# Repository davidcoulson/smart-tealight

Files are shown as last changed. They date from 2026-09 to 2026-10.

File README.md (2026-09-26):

# smart-tealight

A rechargeable, 38 mm tea-light replacement with addressable LEDs, built on a
Seeed XIAO module, controlled from Home Assistant.

* **Fits a standard tea-light holder:** 38 mm Ø, ≤ 23 mm tall, 3D-printed PETG body
* **Battery powered:** ~400 mAh LiPo, charged over the XIAO's USB-C
* **Two light channels:** an 8-LED addressable ring for effects, and a single
  warm-white LED for a low-power flickering "candle" mode that lasts a week
* **Two firmware tracks on the same hardware:**
  * *Track A* — XIAO ESP32-C6 + [ESPHome](esphome/tealight-c6.yaml). Quick to
    build, ~½ day on battery because Wi-Fi stays associated. For prototyping.
  * *Track B* — the same XIAO ESP32-C6, [ESPHome over Thread](esphome/tealight-c6-thread.yaml)
    via the HA OpenThread Border Router. **Working on the bench (2026-09-26).**
    Next: sleepy end device + light sleep for weeks of standby.

**Status: design stage.** No hardware has been built; all current and battery
figures are estimates to be measured on the first prototype.

## Docs

* [Design notes](docs/design-notes.md) — prior art, power budget, mechanical
  stack, pin plan, bill of materials (Amazon US), firmware behaviour, next steps
* [Shopping list](docs/shopping-list.md) — Amazon US listings for every part
* [Wiring schematic](docs/wiring.svg) and [perfboard layout](docs/perfboard.svg) (generators alongside)

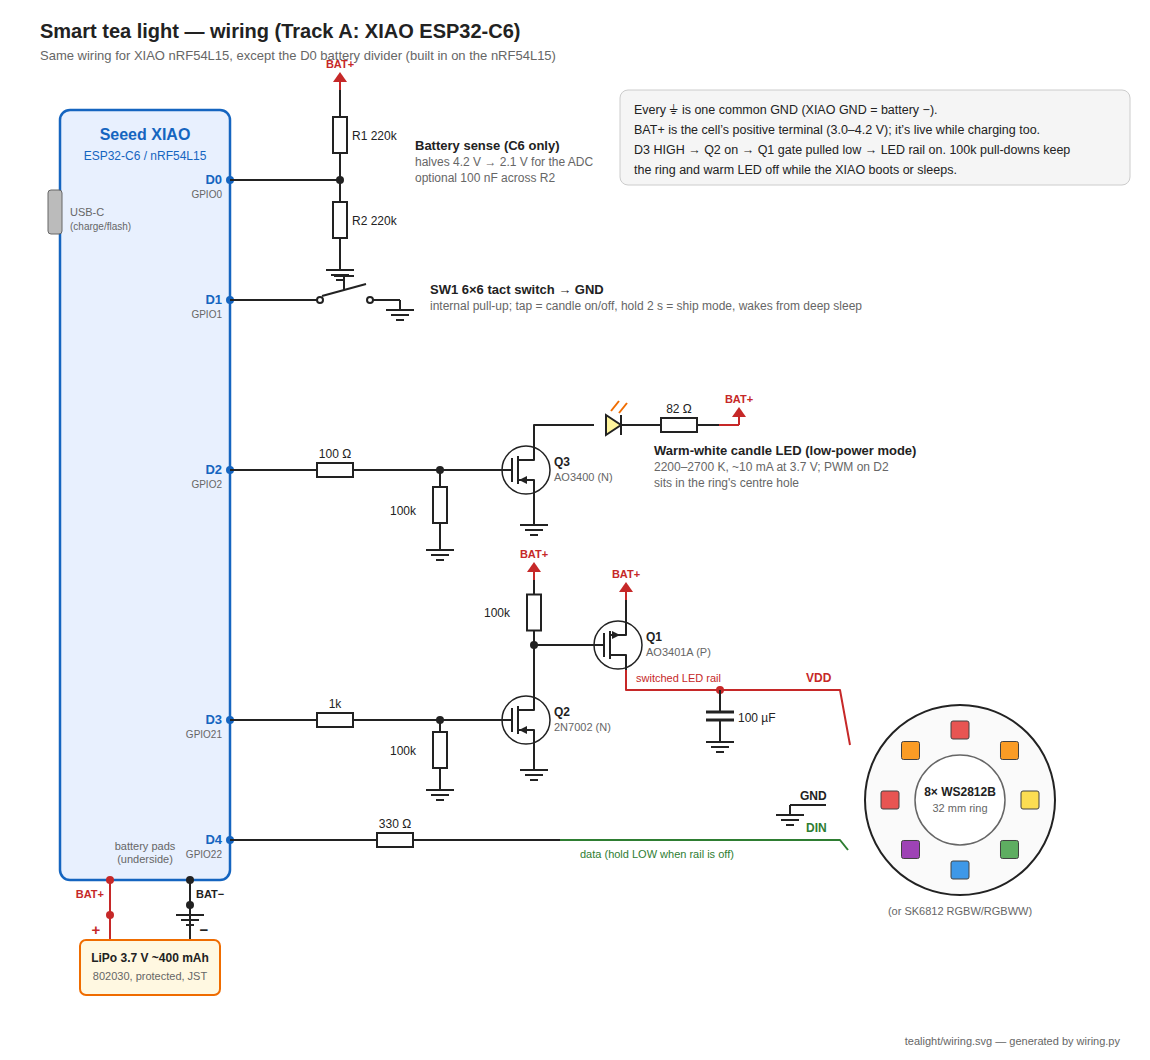
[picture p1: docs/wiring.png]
Wiring


## Repo layout

```
docs/       design notes, schematic and its generator
esphome/    Track A ESPHome config (XIAO ESP32-C6)
firmware/   fallback only: matter-thread-test/ (ESP-Matter procedure, not used)
hardware/   3D-printable body, later a custom LED PCB (to come)
```

## License

MIT — see [LICENSE](LICENSE).

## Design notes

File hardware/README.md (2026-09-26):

# Body — 3D-printed parts

`tealight.scad` is the source (parametric; every dimension at the top).
Three parts:

| Part | Material | Notes |
|---|---|---|
| `cup.stl` | opaque PETG | battery, perfboard ledge tabs, XIAO, USB-C notch (+x), Ø4 button hole in the floor |
| `carrier.stl` | opaque PETG | 4.5 mm spacer on the perfboard that carries the 32 mm LED ring; cut away over the XIAO |
| `cap.stl` | translucent PETG | diffuser, 2 mm plug skirt into the cup, notched for the USB-C |

Total height 23.0 mm, Ø38. Stack: floor 1 · cell 8.5 · perf 1.6 · XIAO 4 ·
ring 3.5 · headroom 2.9 · top 1.

Render: `openscad -D 'part="cup"' -o cup.stl tealight.scad` (same for
`carrier`, `cap`; `part="all"` with `exploded=true` for a preview).
`preview.py` is a manifold3d port used to produce the STLs and
`preview.png` where OpenSCAD isn't available; keep it in sync with the .scad.

**Untested — first print is a fit test.** Things to check on it: the 802030
cell's corners against the Ø36 bore, the USB-C notch height (12–15.5 mm)
against the real XIAO on the perfboard, and the cap's plug fit (0.2 mm
clearance; PETG usually wants 0.2–0.3).

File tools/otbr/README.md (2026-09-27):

# OTBR on a Linux box (USB RCP)

1. Flash `firmware/nrf52840-rcp` onto a XIAO nRF52840 (double-tap reset →
   `adafruit-nrfutil dfu serial --package rcp.zip -p /dev/cu.usbmodem101 -b 115200 --singlebank`)
   and plug it into the Linux box. It enumerates as "Thread RCP nRF52840",
   `/dev/ttyACM0` (check `ls -l /dev/serial/by-id/`).
2. `BACKBONE=<lan-if> docker compose up -d` in this directory.
3. Form a network once (the container keeps it in the `otbr-data` volume):
   `docker exec otbr ot-ctl dataset init new && docker exec otbr ot-ctl dataset commit active && docker exec otbr ot-ctl ifconfig up && docker exec otbr ot-ctl thread start`
   then `docker exec otbr ot-ctl state` → `leader`.
4. Home Assistant → Settings → Devices & services → Thread: the new border
   router appears (mDNS `_meshcop._udp`) → "Make preferred network".
5. Sanity check with the OT CLI board (`firmware/nrf52840-otcli`): join with
   `docker exec otbr ot-ctl dataset active -x`, `ot mode -`, 50 pings to the
   BR's ML-EID (`docker exec otbr ot-ctl ipaddr mleid`) — expect ~100 %.

Web UI: http://<box>:80, REST: http://<box>:8081/node.

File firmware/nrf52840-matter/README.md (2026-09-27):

# nRF52840 (XIAO BLE) — Matter over Thread, sleepy end device

Same app as `../nrf54-matter` (Nordic `light_bulb`, NCS v3.2.4) ported to the
**Seeed XIAO nRF52840** as the stand-in while the nRF54L15 is backordered.
Builds: 723 KB of the 784 KB app partition, 64 % RAM. **Boots and advertises Matter
over BLE on the XIAO nRF52840** (2026-09-27); commissioning is the next test.

Board specifics:
- `boards/xiao_ble_nrf52840.overlay` — PWM light on **P0.04 = D4**, console on the
  chip's own USB CDC ACM (the XIAO BLE has no debug probe), a `buttons` node on D5
  (Nordic's Matter glue requires one; nothing needs to be wired), die-temp sensor.
- `pm_static_xiao_ble_nrf52840.yml` — the board's Adafruit-bootloader layout
  (app at 0x27000 after MBR + SoftDevice reservation). It still reserves a 4 KB
  `factory_data` slot, but **factory data is off** (`CHIP_FACTORY_DATA=n`): the
  Adafruit bootloader only flashes the app image, so a generated factory-data
  partition never reaches the chip and the app sat silent at boot waiting for it.
  The build uses the CHIP test identity instead (VID 0xFFF1, PID 0x8005,
  discriminator 3840, passcode 20202021 — code `34970112332`).
- `prj.conf` additions — legacy USB stack only (`USB_DEVICE_STACK_NEXT=n`, both were
  linking), **MTD OpenThread library** (`OPENTHREAD_MTD=y`,
  `OPENTHREAD_NORDIC_LIBRARY_MTD=y` — the FTD set has no MTD lib), shells off, QSPI
  NOR off (unused, and it drags in an external-flash factory-data provider).

Build:
```sh
cd /opt/nordic/ncs/v3.2.4
nrfutil sdk-manager toolchain launch --ncs-version v3.2.4 -- \
  west build -p always -b xiao_ble/nrf52840 -d <this dir>/build <this dir> -- \
  -DSB_CONFIG_BOOTLOADER_NONE=y -DSB_CONFIG_MATTER_OTA=n -DSB_CONFIG_MATTER_FACTORY_DATA_GENERATE=n
```

Flash (double-tap reset first → green LED pulses, `XIAO-SENSE` mounts), either:
```sh
# serial DFU (what worked; the zip is made by the build)
adafruit-nrfutil dfu serial --package build/nrf52840-matter/zephyr/tealight.zip \
  -p /dev/cu.usbmodem101 -b 115200 --singlebank
```
or copy `build/nrf52840-matter/zephyr/zephyr.uf2` onto the `XIAO-SENSE` drive.
The board reboots as a "Tealight nRF52840" USB serial device carrying the log
(115200; on macOS it enumerates as a *new* `cu.usbmodem` port, not the bootloader's).
Commission: HA companion app → Settings → Devices → Add device → Matter, code
`34970112332` (BLE, so it has to be the phone app or a Matter server with a
Bluetooth adapter — the HA server's "Add device" only works if the host has BT).

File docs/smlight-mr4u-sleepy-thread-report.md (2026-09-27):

> **2026-09-27, later: DO NOT FILE.** The same failure reproduces with an SLZB-06
> (CC2652P) over USB on a separate Linux OTBR — see Finding 9 in
> `thread-sed-bisect-2026-09-26.md`. The MR4U is not the cause.

# SLZB-MR4U: Thread sleepy end devices cannot attach (indirect / CSL tx fails)

Report for SMLIGHT support — 2026-09-27.

## Summary

With the SLZB-MR4U's EFR32MG26 as the Thread radio, **rx-on Thread children work
but sleepy end devices (SED/SSED) never attach**: the border router queues the
Child ID Response for the sleeping child and every indirect (data-poll)
transmission fails, 4/4 attempts, on every attach. CSL (synchronized sleepy)
fails the same way. This happens both with the MR4U's built-in OTBR and with the
MR4U used as a network RCP by the Home Assistant OpenThread Border Router add-on
(stable and beta otbr-agent). Net effect: no battery-powered Matter-over-Thread
device can be commissioned through this radio.

## Hardware / firmware

| | |
|---|---|
| Device | SLZB-MR4U (hw 174), Ethernet mode, IPv6 "Off" in device settings, USB = debug port |
| Device firmware | v3.4.1.dev1 (dev channel) |
| Radio 1 | EFR32MG26, mode "Matter-over-Thread", firmware **20260416 (Dev)** — "Thread test firmware designed to fix problems with OTBR starting after device reboot" |
| RCP reported by otbr-agent | `SL-OPENTHREAD/3.0.1.0_GitHub-61e43cffb; EFR32; Apr 16 2026 06:14:46` |
| Radio 2 | CC2674P10, Zigbee coordinator (Zigbee2MQTT over tcp://10.2.4.5:7638) |
| Border router (config A) | MR4U built-in OTBR, network `SLZB-d6b5`, channel 15 |
| Border router (config B) | HA OpenThread Border Router add-on 3.2.0 on HA OS 18.3 (x86-64 VM), `network_device: 10.2.4.5:6638`, backbone `enp6s19` (same VLAN as the MR4U), tested with `beta: true` and `beta: false`; network `ha-thread-c912`, channel 15 |
| Test client | Seeed XIAO nRF52840, nRF Connect SDK v3.2.4 OpenThread CLI (`OPENTHREAD/ncs-thread-reference-20250402`), TX 0 dBm, same room; also an ESP32-C6 (ESPHome openthread) and the nRF52840 running Nordic's Matter `light_bulb` sample — all show the same behaviour |

Link quality between the MR4U and the test client is excellent in every test
(`ot parent`: Link Quality In 3 / Out 3; MR4U hears the client at about −68 dBm).

## Config A — MR4U built-in OTBR

Client joined as an rx-on MTD child (`ot mode rn`):

| test | result |
|---|---|
| attach | OK, parent = MR4U (RLOC 0xe000) |
| `ot ping <BR RLOC fd50:…:0:ff:fe00:e000>` ×10 | 9/10 answered, 23–51 ms, hlim 64 |
| `ot ping <BR mesh-local EID fd50:…:810:effc:8ad7:1b82>` (the SRP server address) ×10 | **2/10 answered**, hlim 255 |
| `ot srp client` registration of `_matter._tcp` | never reaches *Registered* (Adding → Refreshing forever) |

Consequence: a Matter device (Nordic light_bulb on nRF52840, sleepy or not)
gets through BLE commissioning, attaches to Thread, then logs
`SRP update error: timed out waiting on server response` ~14 times in a row (one
random success), so operational discovery fails and the commissioner's
fail-safe expires ("Commissioning failed: 32"). ESP32-C6/ESPHome behaves the
same as an MTD; as an FTD it happens to work.

## Config B — HA OTBR add-on, MR4U as network RCP

Same client, rx-on MTD child (`ot mode rn`):

| test | result |
|---|---|
| attach | OK, parent = add-on BR (RLOC 0x7000), LQI 3/3 |
| ping BR RLOC ×20 | 18/20, 24–40 ms |
| ping BR mesh-local EID ×20 | 13/20 |
| SRP registration | **Registered** in < 8 s (add-on log: `SrpServer: Send success response with granted lease: 7200`) |

Same client switched to a **sleepy end device** (`ot pollperiod 500`, `ot mode -`):

- `ot state` stays `detached` indefinitely (retested after 15 s, 20 s, and with
  `ot thread stop/start`). The client sends data polls (`TxDataPoll` counter
  increments) and the add-on receives its Child ID Requests.
- otbr-agent log, repeated on every attach attempt:
  ```
  Mle: Receive Child ID Request (fe80::4025:602e:becd:e0ac)
  Settings: Added ChildInfo {rloc:0x7001, extaddr:4225602ebecde0ac, timeout:240, mode:0x04, version:5}
  Mle: Send Child ID Response (fe80::4025:602e:becd:e0ac,0x7001)
  DataPollHandlr: Indirect tx to child 7001 failed, attempt 1/4
  DataPollHandlr: Indirect tx to child 7001 failed, attempt 2/4
  DataPollHandlr: Indirect tx to child 7001 failed, attempt 3/4
  DataPollHandlr: Indirect tx to child 7001 failed, attempt 4/4
  ```
- Identical with `beta: false` (stable otbr-agent) and `beta: true`.

Same client as a **synchronized sleepy end device** (`ot csl period 500000`):

- never attaches; otbr-agent log:
  ```
  CslTxScheduler: CSL tx to 7001 failed, attempt 1/4 … 4/4
  ```

Switching the client back to `ot mode rn` → attaches within seconds every time.

## EFR32 firmware 20251218 (Thread RCP 2.7.2.0, SDK 2025.6.2)

Re-flashed radio 1 to the older release build (`SL-OPENTHREAD/2.7.2.0_GitHub-fb0446f53;
EFR32; Dec 18 2025`), OTBR add-on stable, same client:

- sleepy child (`ot mode -`, poll 500 ms) **now attaches** and stays attached;
  SRP registration succeeds while sleepy.
- but delivery to the sleeping child is still poor: 50 pings to the BR's
  ML-EID → 21 answered (42 %), RTT 70 ms – 2.7 s; RLOC similar. otbr-agent
  still logs `Indirect tx to child … failed, attempt 1/4` on most frames, with
  some reaching 4/4 and being dropped. The client's MAC counters show every
  data poll ACKed (`TxAckRequested 675 / TxAcked 675`).
- To rule out host→RCP latency, the client was rebuilt with OpenThread's
  `OPENTHREAD_CONFIG_MAC_DATA_POLL_TIMEOUT` raised from 100 ms to 500 ms
  (radio kept on 5× longer after a frame-pending poll): 17/50 and 20/50 —
  **no improvement**. The queued frame is not reaching the child at all in
  the failing cases, so this is not host-side latency.

So: 3.0.1 build = sleepy children never attach; 2.7.2 build = attach, ~40 %
delivery. Both unusable for battery Matter devices.

## Interpretation

Direct transmissions to an rx-on child work; the two transmission paths that
depend on the RCP (frame-pending / source-address-match after a data poll, and
CSL-timed transmission) fail 100 % on the 3.0.1 build and ~60 % on the 2.7.2
build. Widening the child's listen window does not help, so the frames are
being lost between otbr-agent and the air, not arriving late. The same radio drives the MR4U's own
OTBR, which explains config A's SRP/ML-EID failures as well.

## How to reproduce

1. MR4U radio 1 in "Matter-over-Thread" mode; HA OTBR add-on with
   `network_device: <mr4u-ip>:6638`, form a network.
2. Any OpenThread CLI device (nRF52840 DK/dongle, or `ot-cli-ftd` on an
   EFR32 dev kit): `ot dataset set active <tlvs>`, `ot ifconfig up`,
   `ot thread start`, `ot mode rn` → attaches.
3. `ot pollperiod 500`, `ot mode -` → stays `detached`; watch the add-on log for
   `Indirect tx to child … failed`.
4. Alternatively commission any battery Matter-over-Thread device — it will
   fail after the Thread join.

## Questions for SMLIGHT

- Is indirect (data-poll) and CSL delivery to sleepy children known to be
  broken in the 20260416 EFR32MG26 Thread firmware, or in the network-RCP
  socket path on the MR4U?
- Is there a stable "Matter-over-Thread" firmware for the EFR32MG26 that we
  should test instead of the dev build?

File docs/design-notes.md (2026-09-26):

# Smart tea light — design notes

A 38 mm tea-light replacement: rechargeable, addressable RGB + warm white,
3D-printed body, controlled from Home Assistant singly or as a group.

Status: **design / pre-prototype** (2026-09-26). No hardware built yet. Every
current and runtime figure below is an estimate to confirm with a meter (a
Nordic PPK2 or a USB power meter on the charge port) on the first prototype.

## 1. Prior art — nothing does all of this yet

| Project | What it is | Why it isn't the answer |
|---|---|---|
| [PixelTheater/espcandle-demo](https://github.com/PixelTheater/espcandle-demo) | 38.6 × 20 mm custom PCB stack, ESP32-S3, 20× WS2812 + 2700 K white + red + UV, ESPHome, MIT | **No battery** — USB-C or 6–20 V DC in. Best reference for the LED layout and the ESPHome config |
| [3ative/Smart-Candles](https://github.com/3ative/Smart-Candles) | D1 Mini (ESP8266) wired into store-bought LED candles, ESPHome | Mains-powered via a phone charger, single-colour |
| [rhannink/XIAO-ESP32C6-Zigbee-WS2812B](https://github.com/rhannink/XIAO-ESP32C6-Zigbee-WS2812B) | XIAO ESP32-C6 as a Zigbee colour light over 16 WS2812B | Arduino, not a tea light, mains-powered. Shows the C6 → ZHA light path works |
| [Nordic Matter light bulb sample](https://docs.nordicsemi.com/bundle/ncs-latest/page/nrf/samples/matter/light_bulb/README.html) | Matter-over-Thread light, builds for `nrf54l15dk` | Starting point for the nRF firmware, not a product |

**Conclusion: start our own project.** Nobody has published a battery,
tea-light-sized, HA-integrated addressable light.

## 2. The one hard constraint: "a week on battery" vs Wi-Fi

This drives the whole design, so it comes first.

* The battery that fits is roughly **300–400 mAh** (see §4).
* An ESP32-C6 running ESPHome keeps Wi-Fi associated so HA can reach it.
  Even with `power_save_mode: LIGHT` that costs something like **20–40 mA
  all the time, lit or not.** 400 mAh ÷ 30 mA ≈ **13 hours.** No LED mode
  fixes that — the radio drains the battery on its own.
* An nRF54L15 as a **Thread sleepy end device** (Matter over Thread) polls
  its parent every ~0.5–1 s and averages tens of µA. Standby for a week
  costs ~10–20 mAh. **That's the only way to get "always reachable from HA"
  and "a week on a charge" at this size.**

Your HA already has what the Thread path needs: the **Matter** and
**OpenThread Border Router** integrations are loaded, plus the Thread
integration.

### Update 2026-09-26 (later): ESPHome over Thread works — Matter dropped

Tested the same evening: ESPHome's native **`openthread`** component on the
XIAO C6 attached to the HA OTBR network, registered via SRP, and HA's
ESPHome integration connected to it over Thread (connections arrive from
the OTBR's `wpan0` address; the firmware has no Wi-Fi compiled in). Lights
toggle from HA. So the finished device stays on **ESPHome YAML** — same
entities, effects and OTA — with Thread as the transport. No ESP-Matter,
no C firmware.

Battery: `device_type: MTD` + `poll_period` makes it a sleepy end device
(radio sleeps; ~17 mA today because the CPU stays awake). The
[esp32_pm power-management PR](https://github.com/esphome/esphome/pull/12325)
adds light sleep and was measured at **105 µA average on a C6 running
openthread SED** — that's the missing piece, usable via `external_components`
from the PR branch until it merges. OTA on a sleepy device needs the
`openthread.set_poll_period` action (merged) to wake the radio first.

Config: [`esphome/tealight-c6-thread.yaml`](../esphome/tealight-c6-thread.yaml).
The ESP-Matter procedure in `firmware/matter-thread-test/` is kept as a
fallback only.

### Update 2026-09-26: the ESP32-C6 can do Matter over Thread too

The C6 has an 802.15.4 radio, so the same XIAO ESP32-C6 can run
**Matter over Thread as a sleepy end device** using Espressif's
[ESP-Matter SDK](https://github.com/espressif/esp-matter) (ESP-IDF, C/C++;
not ESPHome, which has no Matter support and no Zigbee `light`). Measured
standby for a tuned Matter light is ~50 µA average
([tomasmcguinness](https://tomasmcguinness.com/2025/01/06/lowering-power-consumption-in-esp32-c6/)),
~230 µA untuned — ≤40 mAh/week, so the week-long goal holds. Espressif's SED
support is younger than Nordic's
([esp-matter #478](https://github.com/espressif/esp-matter/issues/478)).

**Revised plan: one board.** Track A stays ESPHome/Wi-Fi on the C6 for the
prototype; Track B becomes ESP-Matter on the *same* C6 — no module swap. The
nRF54L15 is now a stretch option (3–5× lower sleep floor, more mature Matter
stack), not a requirement. The two-track table below is kept for reference.

### Recommendation: two tracks, one hardware design

The XIAO boards share one footprint and pinout, so the body, LED board and
wiring are identical. Only the module and firmware change.

| | Track A — prototype | Track B — the real device |
|---|---|---|
| Module | XIAO ESP32-C6 | **XIAO nRF54L15** |
| Firmware | ESPHome (starter config in [`esphome/tealight-c6.yaml`](../esphome/tealight-c6.yaml)) | Zephyr / nRF Connect SDK, Matter over Thread, sleepy end device |
| HA integration | ESPHome API over Wi-Fi | Matter (via your OTBR) |
| Standby life | ~½ day | weeks |
| Effects | ESPHome built-ins, no code | Written in C (flicker, rainbow, etc.) and picked through a Matter *Mode Select* endpoint → HA `select` entity |
| OTA | ESPHome OTA over Wi-Fi | MCUboot + SMP over BLE (nRF Connect Device Manager app); Matter OTA later |
| USB flash | yes | yes — the XIAO nRF54L15 has an on-board debug probe on USB-C |
| Why | Tests the LEDs, body, battery and effects in an afternoon | Meets the battery goal |

Build Track A first to sort out the physical design, then swap modules.

**If the XIAO nRF54L15 isn't in stock:** the **XIAO nRF52840** (widely stocked on
Amazon US, ~$10) does the same job. Nordic supports Matter over Thread on the
nRF52840 in NCS, and the XIAO's 2 MB QSPI flash (P25Q16H) covers the external
flash Matter DFU needs — the NCS lighting sample needs a board overlay for it
(see [Nordic DevZone: Matter with XIAO nRF52840](https://devzone.nordicsemi.com/f/nordic-q-a/97985/matter-with-seed-xiao-nrf52840)
and [felix920506/nrf52840-battery-button](https://github.com/felix920506/nrf52840-battery-button),
a battery Matter-over-Thread device on exactly this board). Costs vs the
nRF54L15: ~2× the sleep current (still tens of µA — irrelevant next to the
LEDs), no built-in battery sense (so keep the D0 divider), and an older, larger
SoC, with 1 MB internal flash that Matter fills most of.

**Ruled out for now:** ESPHome on nRF52/XIAO nRF52840. ESPHome's nRF52 port
has no native HA API (no Wi-Fi), and its Zigbee component (added in 2026.1)
exposes only binary_sensor, sensor, switch and number — **no `light`**. Worth
checking again later; it would give ESPHome YAML with Zigbee battery life.

## 3. Power budget (estimates)

Usable capacity is ~340 mAh from a 400 mAh cell (stopping at 3.5 V).

| State | Draw | Hours from 340 mAh |
|---|---|---|
| nRF54L15, Thread SED standby, LED rail **off** | ~0.05–0.1 mA | months |
| ESP32-C6, Wi-Fi associated, LEDs off | ~20–40 mA | ~10–15 h |
| Addressable LEDs powered but **black** | ~0.6–1 mA **per LED** | — (why the LED rail must be switched off) |
| **Low-power candle mode**: one warm-white LED, PWM flicker, ring rail off (nRF) | ~3–5 mA | **~70–100 h** |
| 8× SK6812 warm, ~10 % brightness (nRF) | ~15–25 mA | ~15–20 h |
| 8× SK6812 full white | ~400+ mA | beyond what the cell can supply — **cap brightness in firmware** |

So "a week" on the nRF track is about **10 h/day of candle mode** or **2–3 h/day
of addressable effects**. That's what the fixed-colour low-power mode is for.

Two design rules follow:

1. **Switch the addressable LEDs' power off** whenever they're dark (a
   high-side MOSFET, §5). WS2812/SK6812 chips draw 0.6–1 mA each just being
   powered. 8 LEDs on a live rail would use up a week's standby budget in a day.
2. **Cap brightness** in firmware (ESPHome `color_correct`) so a full-white
   command can't pull more than the cell or the XIAO charger can take.

## 4. Mechanical stack (38 mm Ø, ≤ 23 mm)

Walls 1.0 mm → **36 mm usable inner diameter**.

```
 z (mm)
 23 ┬─ diffuser dome top (1 mm translucent PETG)
    │  air gap ~3–4 mm (helps diffusion)
 18 ├─ LED board: 32 mm 8-LED ring, or a 144/m strip segment  (~3.5)
 14 ├─ wiring + MOSFETs on a small perfboard / SOT-23 adapters (~1.5)
 13 ├─ XIAO module, USB-C at the side wall                      (~4.0)
  9 ├─ LiPo 802030 (8 × 20 × 30 mm) + 0.5 mm swell room         (~8.5)
  1 ├─ floor (0.8–1 mm) + button / slide switch opening
  0 ┴
```

* **Battery footprint:** 20 × 30 mm has a 36.1 mm diagonal, so it only just
  fits a 36 mm bore (pouch corners are rounded, but test-print first).
  Fallbacks: **602030** (6 mm, ~300 mAh, frees 2 mm) or a **25 × 25** cell.
  Get cells with a protection PCB and a JST-1.25 lead.
* **XIAO placement:** with a 17.8 mm wide board, the side wall is 15.6 mm from
  centre, so the board spans roughly +15.6 → −5.4 mm and the USB-C sticks out
  to a slot in the wall. Keep the antenna end clear of the battery and the LED
  board's copper.
* **Body:** two parts — a cup (PETG, matte black or white) and a snap-fit
  diffuser cap. PETG, not PLA: tea-light holders sit in sunny windows and next
  to real candles.
* **Diffuser:** *translucent* (natural) PETG looks better than *clear*. Clear
  shows every LED as a hotspot. Print the dome in vase mode, 0.8–1 mm. An
  optional flame-shaped insert over the centre LED looks convincing.

## 5. Electronics

Wiring schematic

Schematic: [`wiring.svg`](wiring.svg) (regenerate with `python3 wiring.py`).

### Pin plan (same XIAO positions for C6 and nRF54L15)

| XIAO pin | C6 GPIO | Use | Notes |
|---|---|---|---|
| D0 | GPIO0 | Battery sense (C6 only) | 2 × 220 kΩ divider BAT+ → D0 → GND. The C6 has no built-in battery sense. **The nRF54L15 has one built in** (load-switched), so leave D0 free there |
| D1 | GPIO1 | Push button to GND | An LP GPIO, so it can wake the C6 from deep sleep. Also: local toggle, and long-press for ship mode |
| D2 | GPIO2 | Warm-white LED PWM | Gate of a low-side N-FET (AO3400). LED + resistor from BAT+ |
| D3 | GPIO21 | Addressable LED rail enable | Drives the high-side switch below |
| — | GPIO3, GPIO14 | **Reserved: XIAO C6 RF switch** (not on the header) | GPIO3 low enables the antenna switch, GPIO14 low selects the onboard ceramic antenna. Firmware must drive both low before Wi-Fi/Thread starts or the radio sees nothing. Applies to ESP-Matter too |
| D4 | GPIO22 | Addressable LED data | 330 Ω series resistor. Drive it **low** whenever the rail is off, or the LEDs get phantom-powered through the data pin |

### LED rail switch

A P-FET alone won't work: at BAT = 4.2 V a 3.3 V GPIO can't pull the gate high
enough to switch it off. Use the standard two-transistor high-side switch:

```
BAT+ ──┬──────────── S  AO3401A (P-FET)  D ─────── LED ring VDD (+ 100 µF)
       │                 G
      100k               │
       └─────────────────┤
                         D  2N7002 (N-FET)
GPIO21 ── 1k ────────── G
                         S ── GND
```

### LEDs — pick one

| Option | Part (Amazon US search term) | Pros | Cons |
|---|---|---|---|
| **A. Off-the-shelf ring + centre warm LED** | "8 bit WS2812 5050 RGB LED ring" (32 mm OD / ~18 mm ID, e.g. Geekstory 2-pack) + a warm-white 2200–2700 K 3 mm or 5050 LED in the middle | No soldering of LED chips; centre hole is exactly where the candle LED goes | RGB only — whites from mixed RGB look bluish and cost 3× the current |
| **B. SK6812 RGBW(W) strip segment** | "SK6812 RGBW warm white 144 LEDs/m" (BTF-LIGHTING etc.) — cut 4 pixels (~28 mm) and lay them across the top, or 2 × 3 in a cross | True warm-white channel on every pixel; a 1 m reel makes a dozen candles | Rectangular layout; strip width ~10–12 mm |
| **C. Hand-built ring** | "SK6812RGBWW 5050 individually addressable chips" (100-pack) on a small custom PCB | Best result: RGB + warm white per pixel in a proper ring | Needs a PCB (JLCPCB, not Amazon) — a good v2 |

**Recommendation:** start with **A** (cheapest, fastest), keeping the separate
warm LED as the low-power candle channel. Move to **C** once the form factor
is settled. SK6812 / WS2812B are 5 V parts but run directly from a 3.5–4.2 V
cell: blue and white dim a little near empty, which the 3.5 V cutoff avoids.
3.3 V data meets V_IH (0.7 × 4.2 V = 2.94 V) even on a full cell.

### Bill of materials (Amazon US, per candle)

| Item | Search term | Notes |
|---|---|---|
| XIAO ESP32-C6 **or** XIAO nRF54L15 | "Seeed Studio XIAO ESP32C6", "Seeed XIAO nRF54L15" | Both have a LiPo charger and battery pads on the back |
| LiPo 3.7 V ~400 mAh, 802030 (or 602030) | "3.7V 400mAh 802030 lipo JST 1.25" | Needs a protection PCB |
| LED ring | "WS2812B 8 bit ring 32mm" | Or the SK6812 options above |
| Warm-white LED | "2200K warm white 3mm LED" or "5050 warm white SMD" | Candle channel |
| AO3401A, AO3400, 2N7002 MOSFETs | "SOT-23 MOSFET assortment" + "SOT-23 to DIP adapter" | Or one tiny load-switch breakout |
| Resistors 100 k, 220 k ×2, 1 k, 330 Ω, ~82 Ω | resistor kit | |
| 100 µF low-ESR cap | "100uF 6.3V tantalum" or ceramic 47 µF 0805 | Across the LED rail |
| 6 mm tact switch (or a tiny slide switch) | "6x6x3.1 tactile switch" | Bottom of the body |
| Filament | translucent (natural) PETG + black/white PETG | |

### Perfboard build (prototype)

Perfboard layout

[`perfboard.svg`](perfboard.svg) (generate with `python3 perfboard.py`) places
everything on a 34 mm disc cut from 2.54 mm double-sided perfboard (e.g. the
4 × 6 cm board from a Rindion 32-pack). Differences from the schematic, to
suit hand soldering:

* Q2 and Q3 are **2N7000** (TO-92, through-hole) instead of SOT-23 parts —
  only the P-FET Q1 needs a SOT-23 adapter. 2N7000 is fine here: Q3 carries
  10 mA, Q2 only pulls Q1's gate.
* Resistors and C1 are **0805 / 1206 SMD bridging adjacent pads** on the
  underside; 1/8 W axials standing on end also work.
* The XIAO is soldered flat by its castellations to pads F4–L4 / F10–L10 with
  Kapton tape underneath; BAT+/BAT− wires come off its underside pads and
  drop through I7 / I8, where the battery lead also lands. The XIAO's USB-C
  ends ~2 mm inside the wall, so the wall gets a recessed slot (magnetic
  USB-C tips help here).
* Height: floor 1 + cell 8.5 + perf 1.6 + XIAO 4 + ring on 4.5 mm standoffs
  3.5 + dome 1 ≈ 22 mm. Nothing to spare — TO-92s lie flat.

Once the prototype checks out, this becomes a two-layer 34 mm round PCB
(KiCad; JLCPCB/PCBWay) with the XIAO castellated onto it, SK6812 RGBWW
pixels in a ring, the MOSFETs as SOT-23s, and pogo/magnet charging pads.

## 6. Firmware behaviour (both tracks)

* **Two HA light entities per candle:** `Ring` (addressable RGB(W), effects)
  and `Candle` (warm LED, flicker effect = low-power mode). An automation or
  script can switch between them by battery level.
* **Group control:** add the candles to an HA light group (Helpers → Group →
  Light). Effects run locally on each candle, so they don't sync across
  candles. That doesn't matter for flicker (it's meant to look random) but
  would for chases — they'd need a shared trigger or Matter group multicast
  (v2).
* **Battery:** voltage + percentage sensors. Below 3.5 V, force the ring off
  and allow candle mode only. Below 3.4 V, shut down.
* **Ship / storage mode:** an HA button (and a long-press) puts the device
  into deep sleep / System OFF. Only the button wakes it.
* **nRF latency:** a sleepy end device only hears commands on its next poll.
  Use ~1 s polls while dark and switch to fast polling while lit — the LEDs
  dominate power then anyway.

## 7. Things not in the original list

1. **Charging a set of candles.** Plugging USB-C into ten candles a week gets
   old. Options: magnetic USB-C tips (cheap, one per candle), pogo pins on
   the base plus a printed charging tray, or a Qi receiver coil in the base
   (a 5 V Qi receiver ~30 mm fits under the battery if you give up ~1.5 mm of
   height or cell).
2. **A physical switch.** Real tea lights have one, and so should this one
   for storage and for guests with no HA access.
3. **LiPo safety.** Enclosed pouch cell, next to candle holders. Buy cells
   with protection, leave swell room, use PETG, don't charge unattended the
   first few times, and never put one in a holder with a real flame.
4. **Commissioning (nRF):** Matter pairs over BLE with a QR code. Print or
   label the QR/manual code on the base of each unit before you close it up.
5. **Charge indication.** Both XIAOs have a charge LED on the board; route
   light from it to the outside (a thin wall or a light pipe) so you can see
   when it's full.
6. **Unique naming.** Use ESPHome `name_add_mac_suffix` or per-unit
   substitutions, so one firmware image flashes every candle.

## 8. Next steps

- [ ] Order Track A parts + a XIAO nRF54L15 (or nRF52840 if the 54 isn't shipping)
- [ ] Print a fit-test body (CAD: OpenSCAD or build123d so it's parametric — cell size, ring OD, height)
- [ ] Bring up `esphome/tealight-c6.yaml`, measure real currents per mode
- [ ] Start the nRF firmware from NCS `samples/matter/light_bulb`, build as MTD/SED for `xiao_nrf54l15`, add WS2812 (SPI) driver + Mode Select endpoint
- [ ] Move to its own public GitHub repo once there's something to share (this notes repo is private)

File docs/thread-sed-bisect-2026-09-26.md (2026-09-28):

# Thread sleepy-end-device investigation — 2026-09-26

Bench board: XIAO ESP32-C6 (MAC …13:79:FC), ESPHome 2026.9.0, ESP-IDF 5.5.5,
flashed over USB. Border router: HA OpenThread Border Router on an SLZB
dongle, ~10 ft away, network `HomeThread` channel 15.

## Summary

| | |
|---|---|
| Thread + HA (FTD) | works |
| Thread + HA as an **MTD** | works, **with a workaround** (below) |
| `esp32_pm` light sleep | works, innocent |
| Sleepy **attach** | fixed 2026-09-27 via `CONFIG_LWIP_ND6=n` |
| Sleepy **data delivery** | **still broken** — API dies ~70 s in; battery target unmet |

## Finding 1: the external U.FL antenna path is dead

The pigtail is attached, but identical firmware attaches on the onboard
ceramic antenna and never attaches with `external_antenna: true`. Suspect an
unseated U.FL connector or a bad pigtail/antenna. Re-seat it before trusting
any `true` result — an earlier round of this bisect ran on that dead path and
produced wrong conclusions (it is why `esp32_pm` was briefly blamed).
The finished candle uses the onboard antenna anyway.

## Finding 2: ESPHome applies the Thread link mode too early

`OpenThreadComponent::apply_linkmode_()` is called from `openthread_esp.cpp`
*before* the dataset is activated and the stack is started. The stored
`NetworkInfo` is then restored over it (`Read NetworkInfo {... role:router,
mode:` in the boot log), so an MTD ends up advertising
`(rx_on=0, device_type=0, network_data=0)` — i.e. **sleepy** — even when no
`poll_period` is configured and ESPHome's own code intends
`mRxOnWhenIdle = (poll_period == 0) = true`.

Consequence: the device is sleepy from its very first Child ID Request and
the attach never completes:

```
Mle: Send Parent Request to routers      -> Receive Parent Response (OTBR, 0xdc00)
Mle: Send Child ID Request  x3           -> no response
Mac: Frame tx ... error:NoAck, type:Cmd(DataReq), dst:a684372864d85749
Mle: Attach attempt N unsuccessful, will try again in ...
```

It hears the border router fine (Parent Response arrives), so this is not RF
range. Re-asserting the link mode *after* the stack is running attaches as a
child in about one second:

```
[W][ot] forced rx_on_when_idle=1 -> OK
Mle: Receive Child ID Response (OTBR) -> Role detached -> child
[I][openthread] SRP client has started
```

**Workaround, now in `tealight-c6-thread-sed.yaml`:** a 10 s interval that,
whenever the role is `DETACHED`, re-asserts `mRxOnWhenIdle = true`. The
device runs as a Minimal End Device (MTD, radio on) and the same watchdog
recovers it if the link ever drops. Worth reporting upstream.

## Finding 3: sleepy polling does not hold the link — confirmed on two routers

**Update 2026-09-27.** Retested against a brand-new Thread network
(`SLZB-d6b5`, channel 15, PAN 0xd6b5) on a different border router
(extended address a21ff13d0ba4994b at 10.2.4.5), with the old OTBR gone. The
device attaches and runs fine as a MED, and HA drives it normally. Flipping
the sleepy switch, with the serial monitor attached throughout:

```
02:42:49.520  [W][api.connection] Home Assistant ...: Network down; disconnect
02:42:50.906  [W][ot] detached: re-asserted rx_on_when_idle=1 to re-attach
02:42:58.762  [W][component] api cleared Warning flag        (back as MED)
```

It detaches ~1.4 s after the radio stops listening. Identical behaviour to
the original OTBR, on a fresh network with an empty child table, a different
router and different credentials — so **the fault is on the ESP32-C6 /
ESPHome side, not the SLZB RCP and not accumulated network state.**
Interference is also ruled out: 20 MHz Wi-Fi, Thread on channel 15 (the gap
between Wi-Fi 1 and 6), Zigbee 50 MHz away on 25.

### Original single-router finding

With the attach fixed, switching to a 1 s poll (`openthread.set_poll_period`,
which re-applies link mode with `rx_on=false`) drops the device: it detaches
and the polls go unanswered with the same `Cmd(DataReq) ... error:NoAck`.
Since a sleepy child retrieves everything from its parent by polling, and the
parent never ACKs the poll, the link cannot survive.

The MAC-layer ACK window is ~192 µs after transmit, so a plausible cause is
the C6 missing ACKs on radio wake rather than anything in ESPHome — ordinary
frames are received fine, only the tight post-TX ACK is missed. Not proven.

Sleepy mode is exposed as an **experimental switch** (`Sleepy mode
(experimental)`, default off) so it can be retried without reflashing; the
watchdog pulls the device back to MED when it drops.

## Finding 4 (2026-09-27): ND6 was breaking the sleepy attach

Espressif's own `ot_sleepy_device` reference sets **`CONFIG_LWIP_ND6=n`**.
Our builds had it **on**: `esp32_pm` only disables ND6 when `poll_period` is
set at *compile* time, and we set it at runtime, so that guard never fired.
With ND6 on, IPv6 Neighbour Discovery keeps probing; once the radio stops
listening the probes fail, the neighbour goes unreachable and the interface
drops — the `Network down; disconnect` we had been chasing.

Adding it explicitly fixes the detach:

```yaml
esp32:
  framework:
    sdkconfig_options:
      CONFIG_LWIP_ND6: "n"
```

Verified: went sleepy and stayed attached for minutes with no detach and no
watchdog activity, and lights were still controllable from HA immediately
after the transition. Ruled out along the way, all measured not assumed:

* `esp32_pm` / radio sleep — sleepy fails identically with `CONFIG_PM_ENABLE`
  unset entirely.
* RF/range — parent link is **avg RSSI -53..-56 dBm, LQI 3/3 both
  directions** (3 is the maximum).
* `CONFIG_FREERTOS_HZ` — already 1000, matching the reference.
* Child timeout / supervision ([PR #16387](https://github.com/esphome/esphome/pull/16387))
  — that concerns poll periods over 180 s; ours is 1 s.

## Finding 5: data delivery to a sleepy child still fails

With the attach fixed, the device **stays attached** but HA's API connection
dies ~70 s after it goes sleepy, and the device logs *nothing* — it never
sees a disconnect. HA's pings simply stop arriving. So the parent is not
delivering queued (indirect) traffic to the sleepy child, even though the
MLE link is healthy.

This is the same delivery failure as before, one layer up: previously it
killed the attach, now it kills the data path.

Auto-sleepy is therefore **disabled** in `tealight-c6-thread-sed.yaml`; the
`Sleepy mode` switch remains for manual testing, and the detach watchdog
still recovers the device.

Also worth knowing: an OTA/version probe that lands while the device is
sleepy hangs the OTA component for ~170 s and blocks the main loop. Turn
Sleepy mode off before any OTA.

## Where this leaves battery life

An MED keeps its radio in RX permanently — tens of mA — so `esp32_pm` light
sleep saves little on its own. **The week-long target is unmet and blocked on
Finding 3.**

Next things to try:
1. A different Thread router (an Apple/Google border router, or a second C6 as
   an FTD parent) to establish whether the failure is the SLZB RCP or the C6.
2. A longer poll period (5–10 s) — fewer polls, but the same ACK problem.
3. `CONFIG_IEEE802154_*` timing/sleep options on the C6.
4. Failing all that: the nRF54L15 (backordered), whose Thread stack is mature,
   or accept mains/USB power for the tea light and keep battery for later.

## Current state of the bench board

`tealight-c6-thread-sed.yaml` — MTD + attach watchdog + `esp32_pm` light
sleep, online in HA over Thread, lights verified from HA. Sleepy switch off.

## On writing our own power-management component

Not needed. `esp32:` accepts raw `sdkconfig_options` (user values take
precedence) and the runtime half is one `esp_pm_configure()` call from an
`on_boot` lambda — ~15 lines, no external component. `esp32_pm` from
[PR #12325](https://github.com/esphome/esphome/pull/12325) already works, so
this is only worth doing to drop the PR dependency.

## 2026-09-27 — Finding 6: it was the border router, not the C6

Retested with the nRF52840 (Nordic Matter light_bulb as sleepy ICD, then the
same with ICD off, then a bare OpenThread CLI — `firmware/nrf52840-otcli`).

- Matter build, sleepy **and** non-sleepy: attaches as CHILD, every SRP update
  "timed out waiting on server response" (1 success in ~14), commissioner
  never finds the node, fail-safe expires. Identical to the C6 MTD symptoms.
- OT CLI as an rx-on MTD child of the **SLZB-MR4U** (fw v3.4.1.dev1, the only
  router/leader, link quality 3/3):
  - ping BR RLOC `…:0:ff:fe00:e000` → 9/10, ~30 ms, hlim 64
  - ping BR ML-EID `…:810:effc:8ad7:1b82` (SRP server) → **2/10**, hlim 255
  - `srp client` registration never reaches Registered.

The two hop limits mean the RLOC is answered inside the OT core and the
ML-EID by the MR4U's host IP stack; the OT→host forwarding path on the MR4U
drops ~80 %. SRP (and therefore Matter commissioning) depends on that path.
Findings 3–5 blaming the C6 sleepy implementation are withdrawn: the C6 FTD
only "worked" because it happened to survive the loss.

Next: run the MR4U as an RCP with the HA OTBR add-on as the border router and
repeat the CLI test.

## 2026-09-27 — Finding 7: the MR4U's Thread radio can't deliver to sleepy children

Moved the border router to the HA **OTBR add-on** (3.2.0) with the SLZB-MR4U's
EFR32MG26 as a network RCP (`10.2.4.5:6638`, SMLIGHT "Matter-over-Thread" dev
firmware 20260416). New network `ha-thread-c912`. Same nRF52840 OT CLI child,
link quality 3/3 both ways:

| child mode | attach | ping BR RLOC | ping BR ML-EID | SRP |
|---|---|---|---|---|
| MED (`rn`, rx-on) | yes | 18/20 | 13/20 | **Registered** in <8 s |
| SED (`-`, poll 500 ms) | never — stays detached | — | — | — |
| SSED (CSL 500 ms) | never | — | — | — |

The add-on log shows why: for the sleepy child the BR queues the Child ID
Response and then logs `DataPollHandlr: Indirect tx to child 7001 failed,
attempt 1/4 … 4/4` on every poll; with CSL it is `CslTxScheduler: CSL tx to
7001 failed, attempt 1/4 … 4/4`. Direct transmissions (rx-on child) work.
Indirect and CSL delivery both rely on RCP radio-firmware features (source
address match / frame-pending, CSL tx scheduling); direct tx does not. So the
sleepy failure is in the MR4U's EFR32 RCP firmware, and it also explains
Findings 3–6 (the MR4U's own OTBR used the same radio).

Consequence: **no sleepy Thread device — ESPHome C6, Nordic Matter ICD, or a
bare OT CLI — can work behind this radio.** Fix is a different Thread RCP
(SMLIGHT stable firmware if it behaves, a Connect ZBT-1/SkyConnect, or an
nRF52840 running the NCS `coprocessor` RCP sample on the HA host's USB).

## 2026-09-27 — Finding 8: EFR32 fw 2.7.2 lets sleepy children attach, ~40 % delivery

Radio 1 re-flashed to SMLIGHT 20251218 (SL-OPENTHREAD 2.7.2.0): the OT CLI SED
attaches and registers SRP, but indirect delivery is 17–21 of 50 pings. Raising
the child's `OPENTHREAD_CONFIG_MAC_DATA_POLL_TIMEOUT` to 500 ms
(`firmware/nrf52840-otcli/overlay-polltimeout.conf`, OT built from source)
changed nothing → not host↔RCP latency. Full write-up for SMLIGHT:
`docs/smlight-mr4u-sleepy-thread-report.md`.

Decision: the MR4U is not a usable Thread border-router radio for sleepy
devices until SMLIGHT fixes it. Use a directly attached RCP for the tea light.

## 2026-09-27 — Finding 9: reproduced with a third, USB-attached radio → not the border router

OTBR (`openthread/border-router` Docker, `tools/otbr/`) on a Radxa Zero 3 with
an **SLZB-06 (CC2652P, SMLIGHT Thread fw 20260304) over USB** — no ESP32
bridge in the path, `TxErrCca 0`. Same nRF52840 CLI child, same network
(`ha-thread-c912`), later moved to channel 25 (energy scan −61 dBm vs −33 dBm
on 15): identical behaviour. Parent log per poll:

```
DataPollHandlr: Rx data poll, src:0x2402, qed_msgs:1, rss:-76, ack-fp:1
Mac: Frame tx attempt 1/1 failed, error:NoAck, len:126, dst:<child ext addr>, sec:yes   (+14 ms)
DataPollHandlr: Indirect tx to child 2402 failed, attempt 1/4
```

Over one 30 s window: parent 17 unACKed indirect frames; child MAC counters
`RxErrNoFrame 1, RxErrOther 1, RxData 11` — the frames are not being aborted,
the child's receiver simply is not listening ~14 ms after its own poll. It does
catch one occasionally (attached once on ch 25), which looks like a race on
the child's RX turn-on after the poll ACK — and would explain why the slower
MR4U 2.7.2 path scored ~40 % while faster paths score ~0 %.

Withdraws Findings 6–8's conclusion that the MR4U is at fault. The SMLIGHT
report (`docs/smlight-mr4u-sleepy-thread-report.md`) must not be filed as-is.

Open experiments: (a) ESP32-C6 ESPHome SED against the same OTBR — flashed
but crash-looped on `esp_openthread_auto_start` (ESP_FAIL) with the new
dataset, not yet debugged; (b) nRF52840 CLI without MPSL
(`overlay-nompsl.conf`) — fails to link; (c) the same child against a
known-good commercial BR (Apple TV "Great-Room" is on the LAN) would settle
child-vs-environment.

Decision (user): MR4U back to running its own OTBR; HA OTBR add-on stopped and
set to manual boot.

## 2026-09-27 — Finding 10: sleepy works on the MR4U's own OTBR at channel 20

Back on the MR4U's built-in OTBR (EFR32 fw 20251218 / OT 2.7.2), network
`SLZB-d6b5` moved from channel 15 (−33 dBm background) to **20** via a
pending-dataset change (active timestamp 2, pushed into HA's store with
`thread/add_dataset_tlv` so the preferred dataset follows).

- ESP32-C6 / ESPHome `tealight-c6-thread-sed.yaml`: attaches, HA API up in
  35 s; **Sleepy mode on (1 s poll)** → MR4U child table `RxOnWhenIdle: 0`,
  API reconnects within 3 s of the mode change and stays up; four HA light
  commands (candle on/off, ring on/off) all delivered and state-verified over
  the next 5 min. This is the first time a sleepy child has worked here.
- nRF52840 OT CLI, same parent/channel, SED poll 500 ms: attaches (LQI 3/3),
  8/30 pings — no longer "never", but still lossy.

Reading of the whole saga: indirect delivery to sleepy children is marginal in
this RF environment and tips from ~0 % to usable depending on channel, radio
firmware and the child's timing. Channel 15 was the worst case for everything.
Remaining work: soak the C6 for hours (API drops?), then the battery current
measurement that started all this.

## 2026-09-28 — Finding 11: the C6 cannot attach as a sleepy end device, full stop

**Finding 10 is withdrawn.** It credited sleepy mode as working because the MR4U
once reported `RxOnWhenIdle: 0` and HA commands succeeded. Commands succeeding
proves the *link* worked, not that the radio slept. A USB power meter settled
it: 60 mA whether "Sleepy mode" was on or off. The radio was never asleep.

Root cause of the illusion: the **attach watchdog had no hysteresis**. It fired
on `DETACHED` and forced `rx_on_when_idle = 1` to recover the boot-time attach
bug. Going sleepy always causes a brief detach, so the watchdog cancelled
sleepy within seconds — and because the switch is `optimistic: true`, HA kept
displaying "Sleepy mode: on" over an always-on radio. Serial capture:

```
[D][main]: Switching to sleepy end device (1 s poll)
[D][openthread]: Link Mode ... RX On When Idle: FALSE     <- applied correctly
[W][api.connection]: Home Assistant ...: Network down; disconnect
[W][ot]: detached: re-asserted rx_on_when_idle=1 to re-attach   <- undone
```

The watchdog is now fixed (15 s tick, 120 s grace when sleepy was requested,
0 s when it was not, and it turns the switch off when it gives up so HA stops
lying). That exposed the real problem.

### The real problem

With the watchdog no longer interfering, a sleepy C6 **never re-attaches**. It
sits at `role=1` (DETACHED) for the entire grace period, every time. Three
configurations, all identical results:

| Configuration | Result |
|---|---|
| runtime switch to sleepy, esp32_pm light sleep on | `role=1` for 120 s, gives up |
| same, with `IEEE802154_SLEEP_ENABLE`, `ESP_PHY_MAC_BB_PD`, `FREERTOS_USE_TICKLESS_IDLE` all verified **off** | `role=1` for 120 s, identical |
| **born sleepy** — `poll_period: 1000ms` at compile time, as Espressif's `ot_sleepy_device` does, `restore_mode: ALWAYS_ON` | `role=1` from boot, still detached at 90 s |

As MED (`rx_on=1`) it attaches in ~1 s and is rock solid. The nRF52840 OT CLI
attaches as a SED to this same parent on this same channel. So the parent
accepts sleepy children; the ESP32-C6 / ESP-IDF OpenThread MTD-sleepy path is
what does not work.

Hypotheses tested and **rejected**:
- USB Serial/JTAG blocking light sleep (`CONFIG_USJ_NO_AUTO_LS_ON_CONNECTION`,
  which `esp32_pm` hardcodes to `True` at power_management.py:134) — the meter
  was on a charger, so no USB host and no enumeration.
- Radio/baseband power-down needing a 32.768 kHz crystal (this board has none:
  `32k XTAL: not in use`) — disabling all three symbols changed nothing.
- Power management generally — it is not involved.

### Consequence for the project

ESPHome-over-Thread on the ESP32-C6 works well as a **mains/always-on** device
and is a dead end for battery. Note also that ESPHome's API is a persistent TCP
connection that HA polls, which is inherently hostile to a device whose inbound
packets depend on a parent's indirect-transmission queue.

The tea light's battery goal therefore rests on the **nRF54L15 + Matter** path
(`firmware/nrf54-matter`), which has a real LFXO and ICD semantics designed for
this. The C6 stays as the working always-on prototype until those boards land.

## 2026-09-28 — Finding 12: nRF54L15 commissioned into HA as a sleepy ICD ✔

Seeed XIAO nRF54L15, `firmware/nrf54-matter` (Nordic light_bulb, MTD + ICD,
1 s slow poll). Border router: HA OpenThread Border Router add-on with the
SLZB-MR4U as network RCP, `ha-thread-c912`, channel 20.

What it took, in order:
1. Build as MTD (`OPENTHREAD_MTD` + `NORDIC_LIBRARY_MTD`) — it was an FTD and
   came up as a ROUTER.
2. Four `/leds` children — the XIAO has one, the app drives DK_LED1..4 → fault.
3. `CHIP_CRYPTO_PSA_MIGRATE_DAC_PRIV_KEY=n` — KMU migration faulted at boot.
4. Matter Server add-on: **Test DCL on** (VID 0xFFF1), **Thread dataset set**.
5. Chip-erase between attempts — stale fabrics give `NoSharedTrustRoots`.
6. BLE TX 0 → +8 dBm (Thread was already +8).
7. **Pre-provision Thread over serial** (`CONFIG_OPENTHREAD_SHELL` + 8 KB shell
   stack; `ot dataset set active <tlv>` / `ot ifconfig up` / `ot thread start`).
   The commissioner reconnects 2 s after `connectNetwork`, before a sleepy
   child's address is registered (`Resolving (address is unreachable)`), then
   hangs on the dead session for 1m41s and the flow dies. Already on the mesh,
   the device opened a CASE session to the HA host itself and HA subscribed.

Evidence: `ot state` child, `ot parent` LQ 3/3, mode `-`, SRP Registered as
`D095D21405F36EEA-000000000000000B._matter._tcp`; HA host `ping6` to the OMR
address ~800 ms (one poll interval); HA device "Matter Light Bulb / Nordic
Semiconductor ASA"; `light.turn_on` / `turn_off` on `light.matter_light_bulb`
verified. Same border router, same channel, same parent — the ESP32-C6 never
got past `role=1`. Next: current measurement on the battery path with the ICD
polling at 1 s (the console/probe must be off for that number to mean anything).

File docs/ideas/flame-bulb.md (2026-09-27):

# Idea: E26 "flame" bulb (Linkind T19 style)

Reference: Linkind Smart Flame bulb — T19 form, Ø57 × 131 mm, E26, 120 V.

Same firmware/HA approach as the tea light (ESPHome, C6; mains-powered so
Wi-Fi is fine — or Thread for consistency), different body:

* **Base:** printed in **PC-FR** (or PC-CF/ABS-FR), carrying an E26 screw
  shell (buy a bulb-repair E26 base) and an **encapsulated, UL-recognised
  AC/DC module** (HLK-10M05, see Power) so the printed
  part only provides mechanics and spacing, never insulation on its own.
  Creepage ≥ 4 mm between mains and low voltage, strain relief on the
  E26 leads, and the module's own thermal limits respected (a T19 in an
  enclosed outdoor fixture gets hot; PC-FR is good to ~110–120 °C).
* **LEDs: SK6812 RGBWW, 144/m, 5 V** (RGB + warm-white die, 7 mm pitch).
  Chosen over WS2805 (RGB+CCT) because WS2805 tops out at 60/m — too coarse
  for flicker — and the dense FCOB WS2805 has one IC per 71 mm. Cool white
  isn't needed for a flame. Ten vertical columns of 10 px (the strip is 12 mm wide; a 10-sided
  mast with 12.2 mm facets leaves ~4.5 mm to the diffuser) — 100 px, XIAO
  inside the core. Body in `hardware/flame-bulb/`. Worst-case white
  ~4 A → cap brightness at ~35 % in firmware. Same reel as the tea light's
  strip option.
* **Power:** 5 V from a **Hi-Link HLK-10M05** (5 V 2 A, 47 × 28 × 22 mm,
  ordered 2026-09-26) standing vertically in the base; the XIAO runs from
  5 V directly, no buck. Design point ≤ 1.5 A continuous (the module gets
  hot near 2 A in a closed body), brightness capped in firmware. Add a 1 A
  slow-blow fuse / fusible resistor on the AC input — the module has none.
  470–1000 µF across the 5 V rail; feed the six LED columns from a common
  5 V ring at the base, not daisy-chained.
* **Diffuser:** translucent PETG tube, Ø57, or a frosted acrylic tube.
* **Effects:** ESPHome addressable_flicker per column with a vertical
  brightness gradient (bright at the bottom, dim at the top) reads as flame.

Open questions: heat (LED + PSU in a closed bulb), whether to skip the
AC/DC altogether and make a 24 V DC version for fixtures we control, and
whether it's worth it vs. the $15 Linkind + Matter.

Parts list: [`../flame-bulb-bom.md`](../flame-bulb-bom.md). Exploded assembly: `../flame-bulb-exploded.png`.

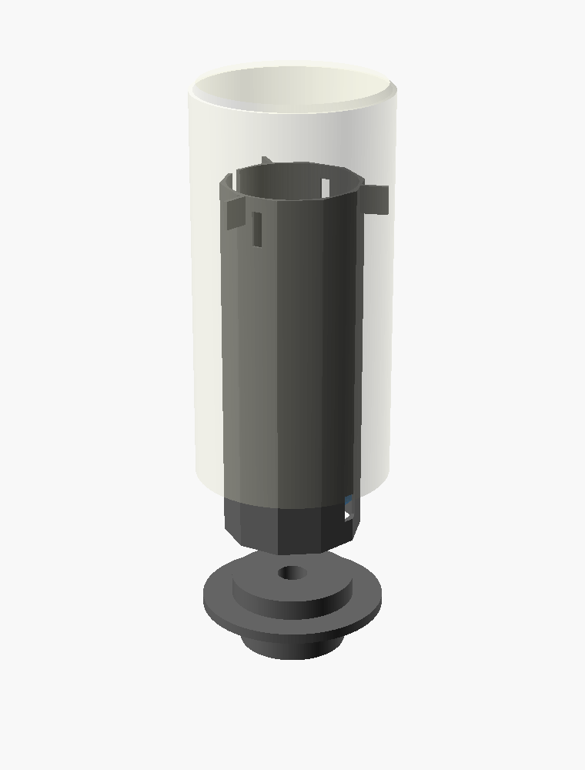
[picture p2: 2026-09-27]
hardware/flame-bulb/preview-v2.png

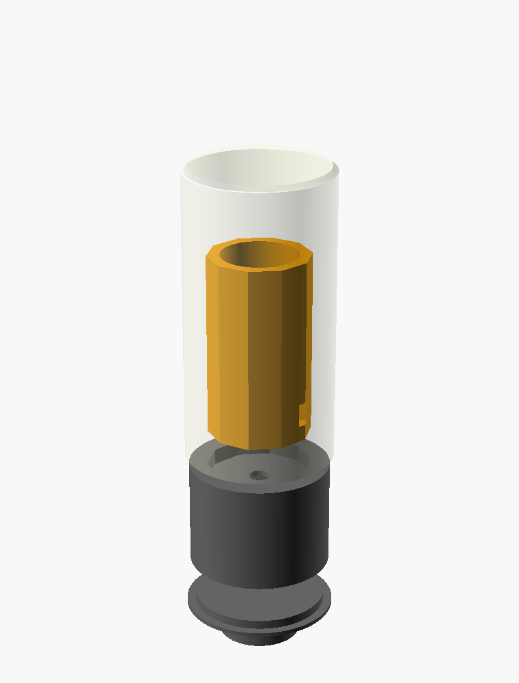
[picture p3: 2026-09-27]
hardware/flame-bulb/preview.png

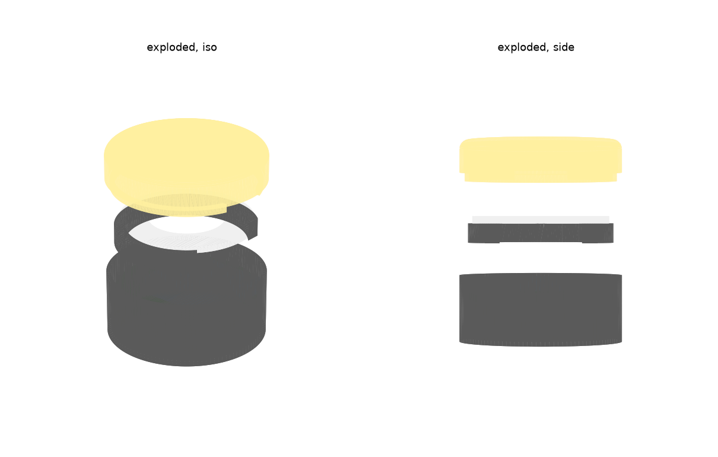
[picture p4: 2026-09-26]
hardware/preview.png

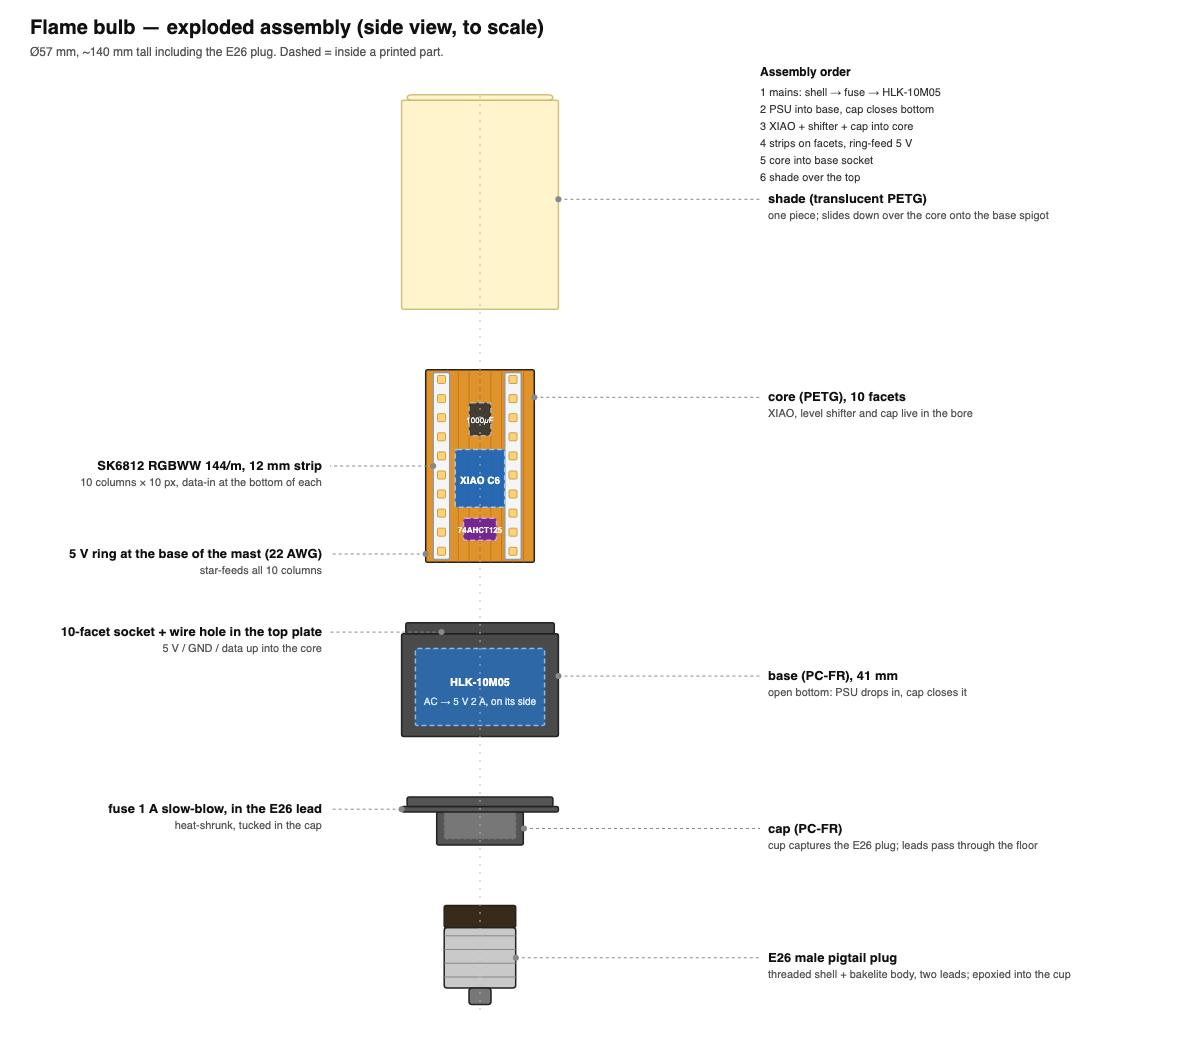
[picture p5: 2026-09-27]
docs/flame-bulb-exploded.png

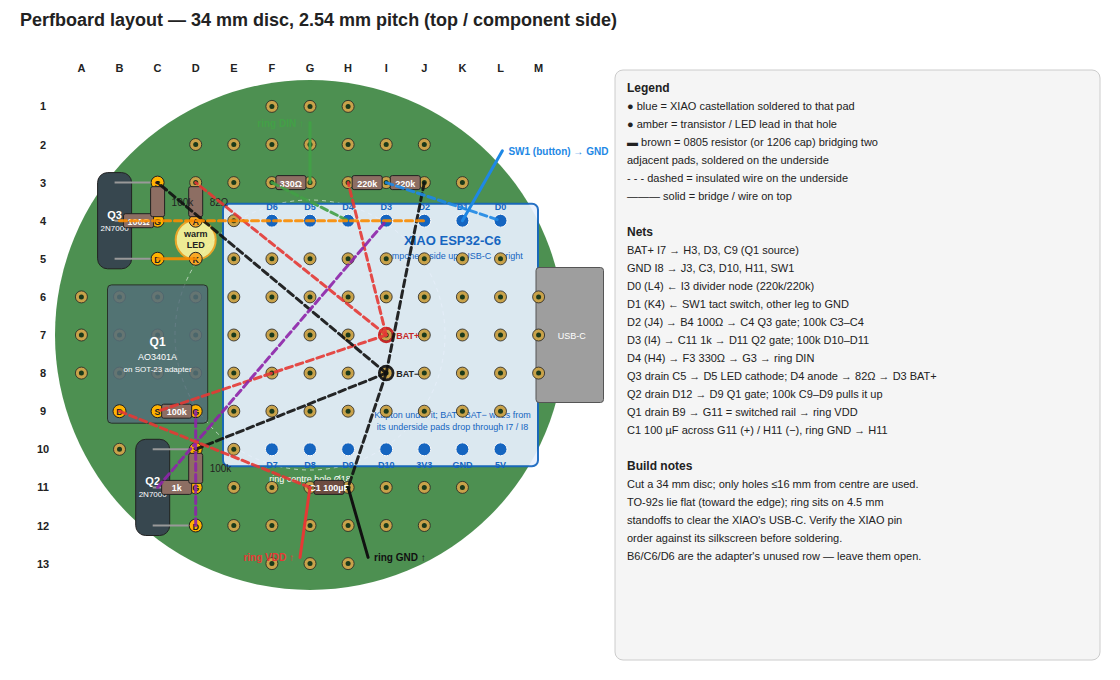
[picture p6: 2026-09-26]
docs/perfboard.png

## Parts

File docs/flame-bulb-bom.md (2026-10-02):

# Flame bulb — parts list

E26, 57 mm diameter, ~140 mm tall (PSU on its side; see `psu_orientation` in the .scad for the ~131 mm Ø59 "flat" option). Body files in `hardware/flame-bulb/`
(`flame-bulb.3mf` has all four printed parts oriented). Design notes in
`ideas/flame-bulb.md`.

Legend: **have** = already owned or ordered from the tea-light work.

## Electronics

| # | Part | Qty | Notes / where |
|---|---|---|---|
| 1 | **XIAO ESP32-C6** | 1 | **have.** Wi-Fi is fine here (mains powered); Thread optional. Sits inside the core bore. |
| 2 | **AC→5 V module** — see note | 1 | **have: HLK-10M05 (2 A)**, 47 × 28 × 22 mm. 150 RGBW px need 1.8 A at a 20 % cap and 2.7 A at 30 %, so with the 10M05 **cap brightness at 20 %**. To keep 30 %: [Mean Well IRM-20-5](https://www.amazon.com/PowerNex-IRM-20-5-Miniature-Encapsulated-Supplies/dp/B017U3FAQ8) (5 V 4 A, 37 × 24 × 15 mm, UL/TUV, ~$14 Prime) — smaller than the HLK in every dimension, drops into the same Ø37 bore; or [IRM-15-5](https://www.amazon.com/PowerNex-IRM-15-5-Miniature-Encapsulated-Supplies/dp/B00HKJTO7E) (3 A). HLK-20M05 listings on Amazon are not Prime. |
| 3 | **SK6812 RGBWW strip, 144 LED/m, 12 mm, 5 V** | 1 m | **have (ordered).** Cut into 10 columns × 10 px (≈70 mm each) = 100 px. Warm-white die is the flame. |
| 4 | **E26 male pigtail plug** (threaded shell on a bakelite body, two leads) | 1 | [BLLNDX 4-pack](https://www.amazon.com/dp/B09WXVXFVT) (the one you found), [Sports Imports SIL-E26-4](https://www.amazon.com/dp/B01LYC0WM1), or [Rextin 5-pack](https://www.amazon.com/dp/B0F9L1PXBT). Body seats in the **cup** on the cap, leads through the floor, epoxied. Measure the body and set `e26_body_d` in the .scad. *Alternative:* a hollow bulb-repair shell (`e26_style = "shell"`, boss cap) — shorter and more bulb-like, but you solder the shell and centre eyelet yourself. |
| 5 | **1 A slow-blow fuse** on the AC input | 1 | The Hi-Link has none. 5 × 20 mm or an axial pigtail fuse; T1A / 250 V. Amazon: "1A 250V slow blow fuse axial leads". |
| 6 | **Level shifter, SN74AHCT125N** (DIP-14) | 1 | **have (ordered).** Required in the bulb: the strip at 5 V wants ≥3.5 V data, the C6 gives 3.3 V. Quad one-way buffer; use one gate, tie its /OE to GND and the three unused inputs + /OE pins to GND. Amazon: "SN74AHCT125N". *Not* a TXS0108E/BSS138 auto-direction shifter — those drive too weakly for the 800 kHz LED stream and flicker. For bench tests the C6 can drive the first pixel at 3.3 V directly over a short wire. |
| 7 | **1000 µF 6.3–10 V electrolytic** across the 5 V rail | 1 | Near the strips' feed point. Amazon: "1000uF 10V electrolytic capacitor". |
| 8 | **330 Ω resistor** in the data line, ¼ W | 1 | From any resistor kit. |
| 9 | **22 AWG silicone wire**, red/black | ~1 m | 5 V power ring to the 10 columns carries up to 1.5 A — **not** the 30 AWG hookup wire. Amazon: "22 AWG silicone wire kit". |
| 10 | **22 AWG 300 V-rated wire** for the mains side | ~0.3 m | E26 shell → fuse → Hi-Link AC pins. Any UL-rated hookup wire. |
| 11 | 30 AWG silicone wire | — | **have.** Data line and low-current runs. |
| 12 | Heat-shrink assortment, Kapton tape | — | Kapton **have.** Insulate every mains joint; sleeve the fuse. |
| 13 | Hot glue or epoxy | — | E26 shell to boss; strips to facets (or double-sided tape). |

## Printed parts

| Part | Material | Qty | Notes |
|---|---|---|---|
| base | **PC-FR** (or ABS-FR / ASA-FR) | 1 | PSU chamber, mains inside. Amazon: "Polymaker PolyMax PC-FR" / "3DXTECH FireX PC-FR". Needs ~270 °C and an enclosure. |
| cap | **PC-FR** | 1 | Bottom cap with the E26 boss. Same spool. |
| core | PETG | 1 | 10-facet mast, opaque. |
| shade | **translucent PETG** | 1 | **have (ordered for the tea light).** One piece, printed closed-end-down. |

## Not needed (for the record)

- No buck converter: the XIAO runs from the 5 V rail directly (5 V pin).
- No battery, no charger, no MOSFET rail switch — the tea light's power-gating
  is irrelevant on mains.
- No BTF connectors: solder directly, the strips are cut segments anyway.

## Power budget

100 px on a 2 A supply. Cap brightness in firmware at **25–30 %**: a flame
effect then averages ~1.5 A; all-channels-full white at 100 % would draw ~5.8 A
and is what the cap exists to prevent. Design point ≤1.5 A continuous so the
Hi-Link stays cool inside a closed body.

## Order of assembly

See `flame-bulb-exploded.png` (generated by `flame-bulb-exploded.py`).

1. Mains: E26 plug leads → fuse → Hi-Link AC-in. Heat-shrink everything.
2. Drop the Hi-Link into the base upright; route 5 V out through the wire hole in the top face.
3. Epoxy the E26 plug into the cap's cup (leads first through the floor hole); press the cap into the base bottom.
4. Wire the XIAO (5 V, GND), level shifter and cap in the core bore; data out via the wire slot.
5. Stick a 10-px strip on each of the 10 facets, all data-in ends at the bottom; daisy-chain data column to column; star-feed 5 V/GND from a ring at the bottom.
6. Plug the core into the base's hex socket; slide the shade down over the core onto the base spigot.

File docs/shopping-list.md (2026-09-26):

# Shopping list (prototype, Amazon US)

Amazon listings found 2026-09-26; check the variant dropdown on each. Quantities
are per *pack* — one pack of each covers many candles.

## Already ordered / owned

| Part | Listing | Notes |
|---|---|---|
| XIAO ESP32-C6 | owned | prototype + Track B (ESP-Matter) |
| XIAO nRF52840 (Meshtastic kit) | ordered | fallback Track B; ignore the LoRa carrier |
| XIAO nRF54L15 | backordered at Seeed | stretch option |
| 8× WS2812B 32 mm ring, 2-pack | [DIYmall B08PCPJSRF](https://www.amazon.com/dp/B08PCPJSRF) | prototype ring |
| SK6812 RGB+**warm white** 5050 chips, 100 pcs | [BTF-LIGHTING B07C1XGD1X](https://www.amazon.com/dp/B07C1XGD1X) | for the v2 PCB (needs hot air / reflow) |
| SK6812 RGBWW 144/m strip, 1 m, IP30, 5 V | BTF-LIGHTING (Amazon, warm-white variant) | tea-light strip option and the flame bulb's columns |
| Hi-Link HLK-10M05 (5 V 2 A AC/DC) | Amazon | flame bulb power |
| Perfboard, 32-pc assortment | [Rindion B0DBZ1BXFZ](https://www.amazon.com/dp/B0DBZ1BXFZ) | cut the 4×6 cm board to a 34 mm disc |

## To order

| Part | Listing | Notes |
|---|---|---|
| LiPo 3.7 V 400 mAh **802030**, with PCM | [AKZYTUE B07TVDPRZK](https://www.amazon.com/dp/B07TVDPRZK) or [Qimoo B0CNLQDLJ2](https://www.amazon.com/dp/B0CNLQDLJ2) | Connector type doesn't matter — it gets cut off and soldered to I7/I8. If the 20×30 footprint won't fit the bore, [802525 (25×25×8.6)](https://www.amazon.com/dp/B0FRFY1F76) is the alternative |
| 2N7000 N-FET, TO-92 | [BOJACK 100 pcs B0831RFJ1B](https://www.amazon.com/dp/B0831RFJ1B) (or [20 pcs B0BJQ92VNT](https://www.amazon.com/dp/B0BJQ92VNT)) | Q2, Q3 |
| AO3401A P-FET, SOT-23 | [Todiys 100 pcs B08RHFLH1K](https://www.amazon.com/dp/B08RHFLH1K) | Q1 |
| SOT-23 → SIP-3 adapter | [Chironal 50 pcs B07MQBF2DD](https://www.amazon.com/dp/B07MQBF2DD) | 3-in-a-row pinout, exactly what the perfboard layout assumes (pads B9/C9/D9) |
| 0805 resistor kit | [Chanzon 1200 pcs / 60 values B08RYMY6XK](https://www.amazon.com/dp/B08RYMY6XK) | covers 82, 100, 330, 1k, 100k, 220k (200k also fine for the divider — just use two of the same) |
| 100 µF 6.3 V tantalum, B (3528) | [Fielect 50 pcs B08BYM7GR8](https://www.amazon.com/dp/B08BYM7GR8) | C1; 3.5 mm body bridges two adjacent pads. Mind polarity (stripe = +) |
| 3 mm warm-white LED, flat-top | [EDGELEC 100 pcs B077XBVZ5Y](https://www.amazon.com/dp/B077XBVZ5Y) | ~3000 K, wide beam, 29 mm leads. Ignore the bundled 6–12 V resistors; use 82 Ω from the kit. Long lead = anode → D4 |
| 6×6×5 mm tact switch | [Taiss 100 pcs B0796QHL5Z](https://www.amazon.com/dp/B0796QHL5Z) | SW1, off-board at the base |
| 30 AWG silicone wire, 6 colours | [TUOFENG B07G2SWB19](https://www.amazon.com/dp/B07G2SWB19) | all the underside jumpers |
| Kapton tape 10 mm | [GoGoRc B0CJQ544H8](https://www.amazon.com/dp/B0CJQ544H8) | under the XIAO |
| PETG, translucent/clear | [Bambu Lab PETG Translucent Clear refill B0FRQ9VX2K](https://www.amazon.com/dp/B0FRQ9VX2K) (Bambu printers) or [MatterHackers Clear PETG B010P3FEY8](https://www.amazon.com/dp/B010P3FEY8) | diffuser dome |
| PETG, black or white | any brand you already use | cup |

## Optional

| Part | Listing | Notes |
|---|---|---|
| Magnetic USB-C tips | [Magtame 24-pin, 4-pack B0DNZCGBBX](https://www.amazon.com/dp/B0DNZCGBBX) + one matching magnetic cable | one tip lives in each candle's recessed USB-C port; charging without fishing for the socket |
| SMD tweezers, flux pen, fine solder (0.5 mm) | — | if not already on the bench |

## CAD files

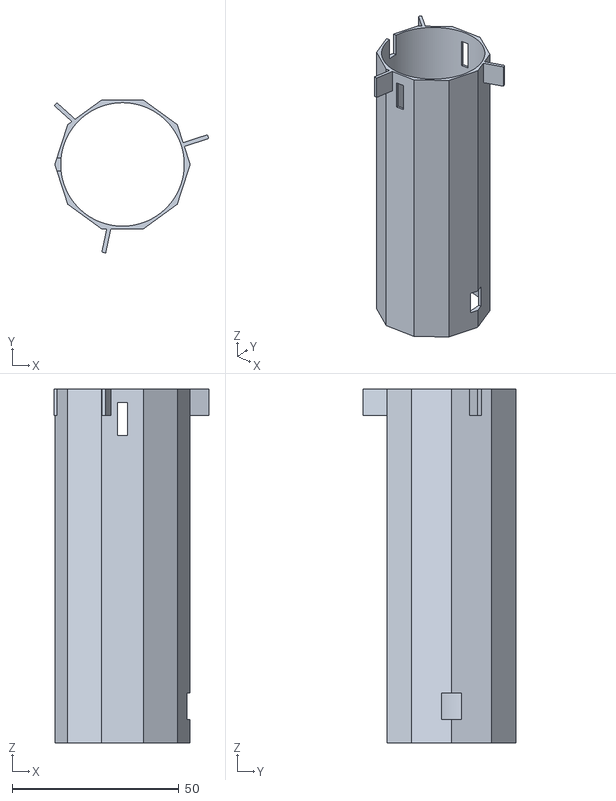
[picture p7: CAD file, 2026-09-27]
hardware/flame-bulb/v2-mast.stl
46.3 x 45.8 x 106.1

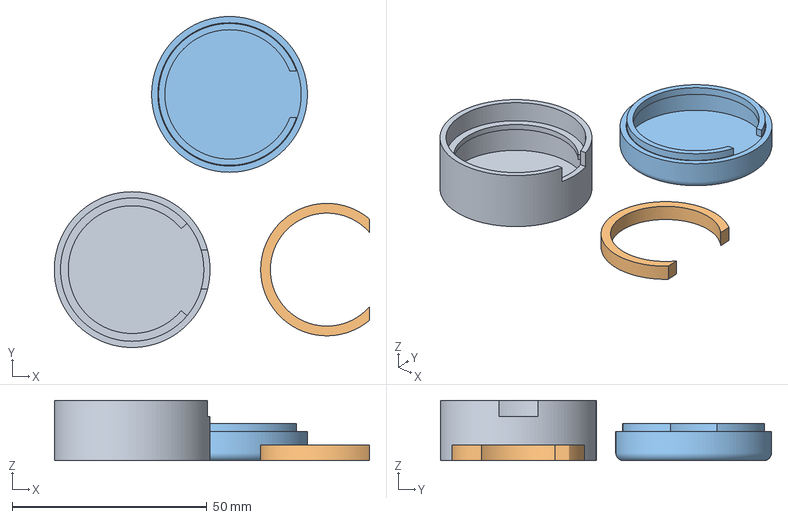
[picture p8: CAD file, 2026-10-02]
hardware/tealight.3mf
81.0 x 85.0 x 15.5 mm
cup
carrier
cap

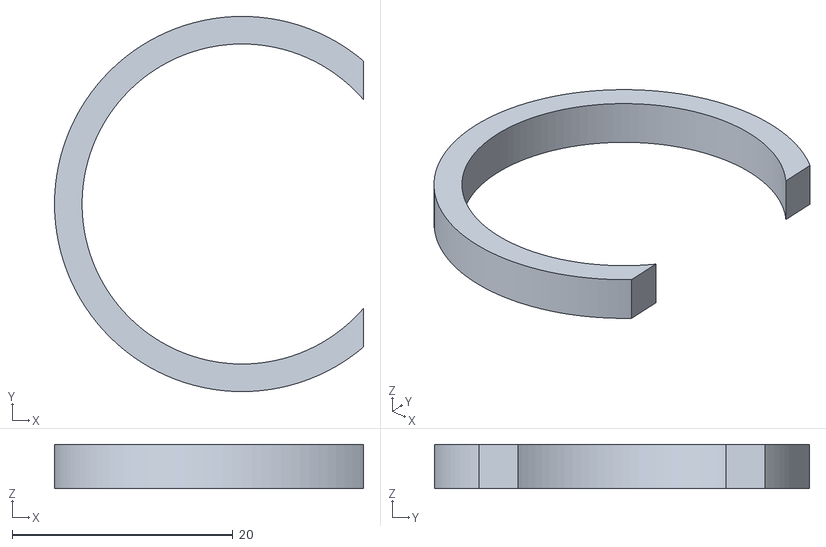
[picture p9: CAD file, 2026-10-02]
hardware/carrier.stl
28.0 x 34.0 x 4.00

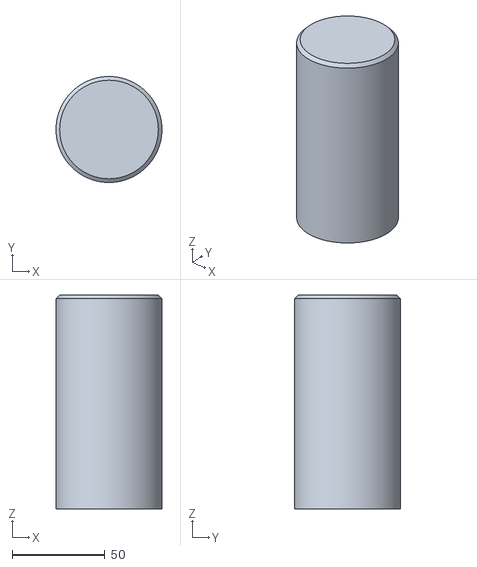
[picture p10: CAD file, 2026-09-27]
hardware/flame-bulb/v2-shade.stl
57.0 x 57.0 x 115.1

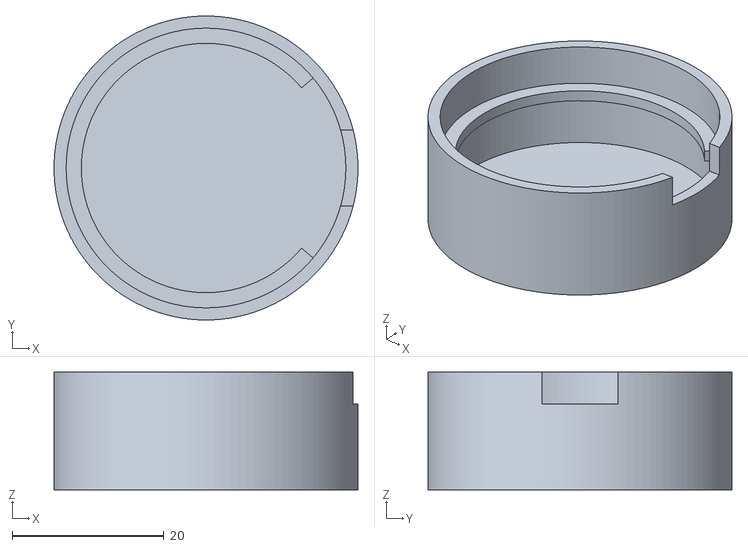
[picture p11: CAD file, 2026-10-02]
hardware/cup.stl
40.0 x 40.0 x 15.5

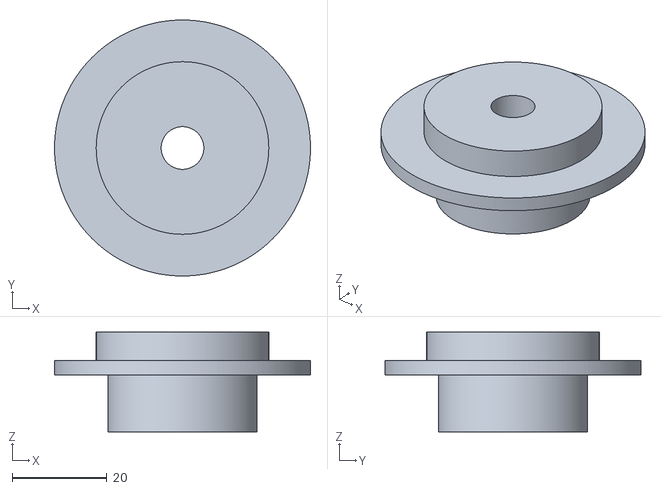
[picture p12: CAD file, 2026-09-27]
hardware/flame-bulb/v2-cap.stl
54.0 x 54.0 x 21.0

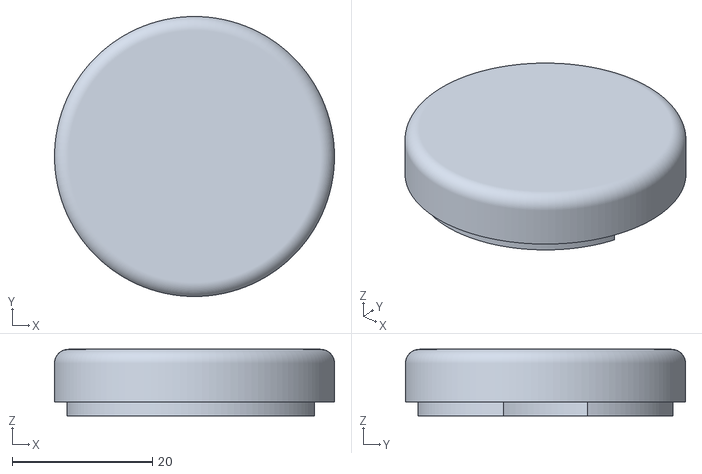
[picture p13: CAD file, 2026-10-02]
hardware/cap.stl
40.0 x 40.0 x 9.50

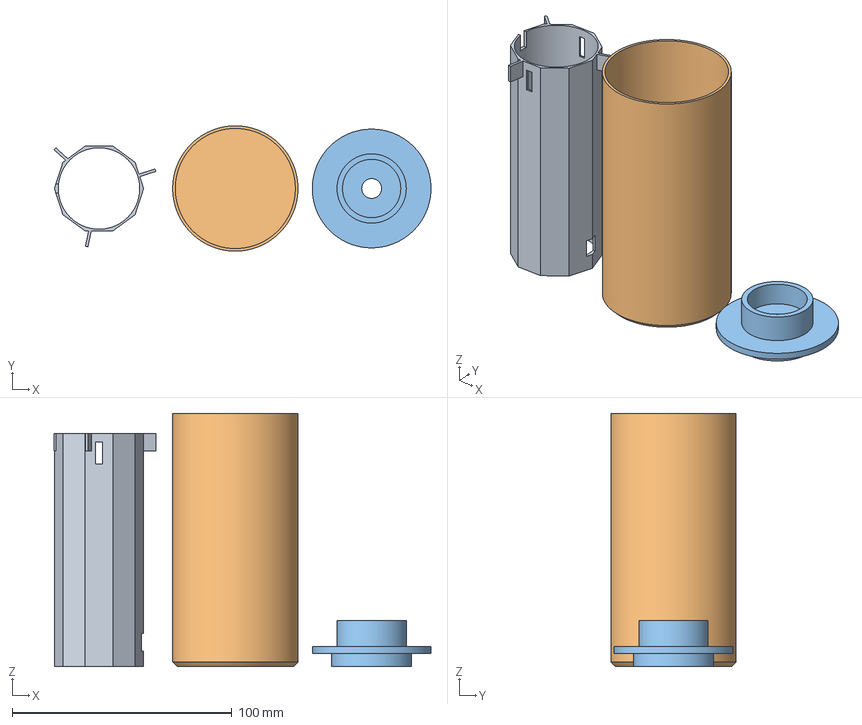
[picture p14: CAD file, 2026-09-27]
hardware/flame-bulb/flame-bulb-v2.3mf
171.5 x 57.0 x 115.1 mm
mast (PC-FR)
shade, full height to the plug (translucent, closed end DOWN)
cap + E26 plug cup (PC-FR)

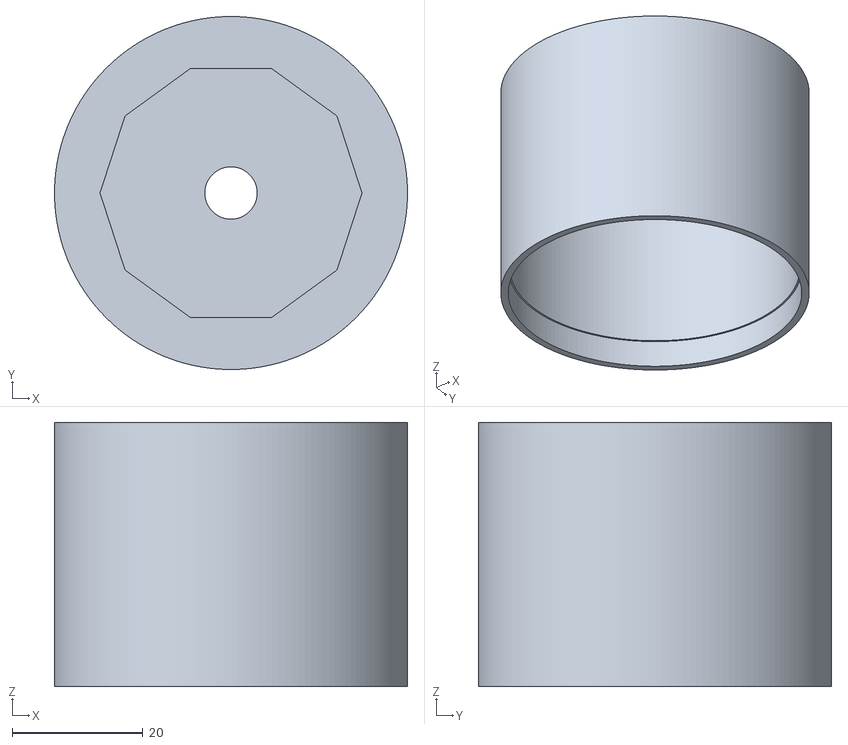
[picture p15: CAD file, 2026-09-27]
hardware/flame-bulb/base.stl
54.0 x 54.0 x 40.4

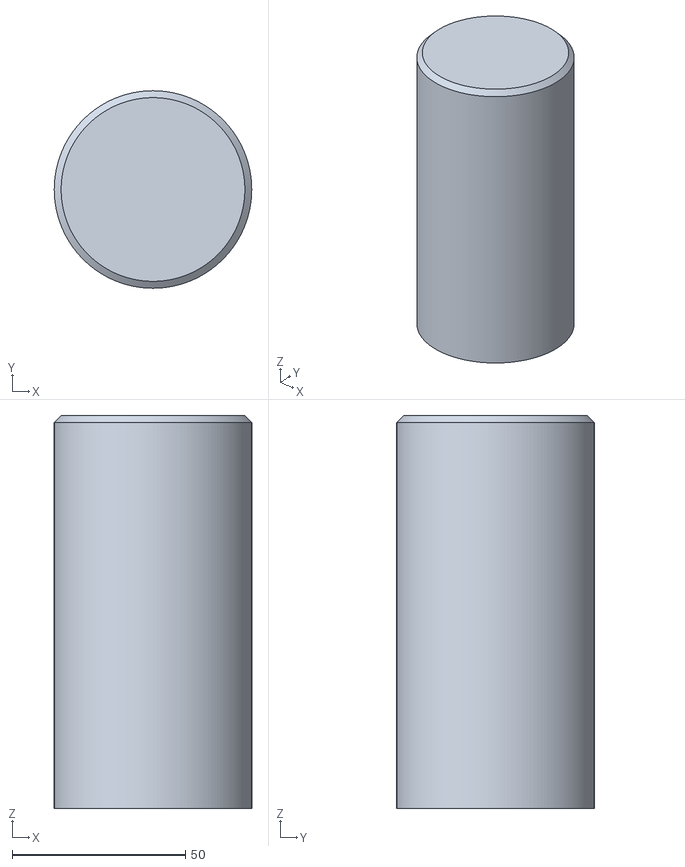
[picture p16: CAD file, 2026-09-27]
hardware/flame-bulb/shade.stl
57.0 x 57.0 x 113.4

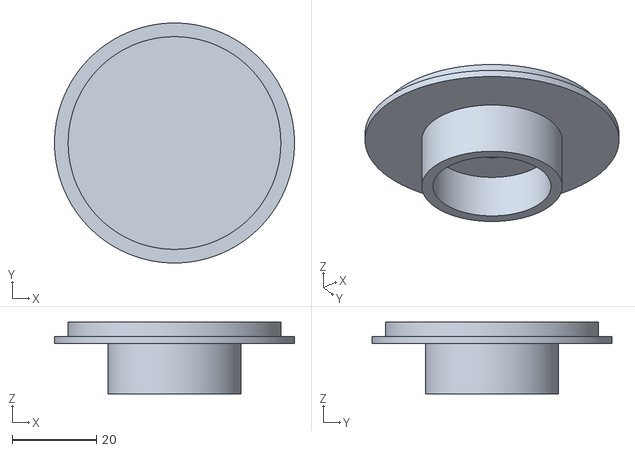
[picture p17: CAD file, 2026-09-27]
hardware/flame-bulb/cap.stl
57.0 x 57.0 x 17.0

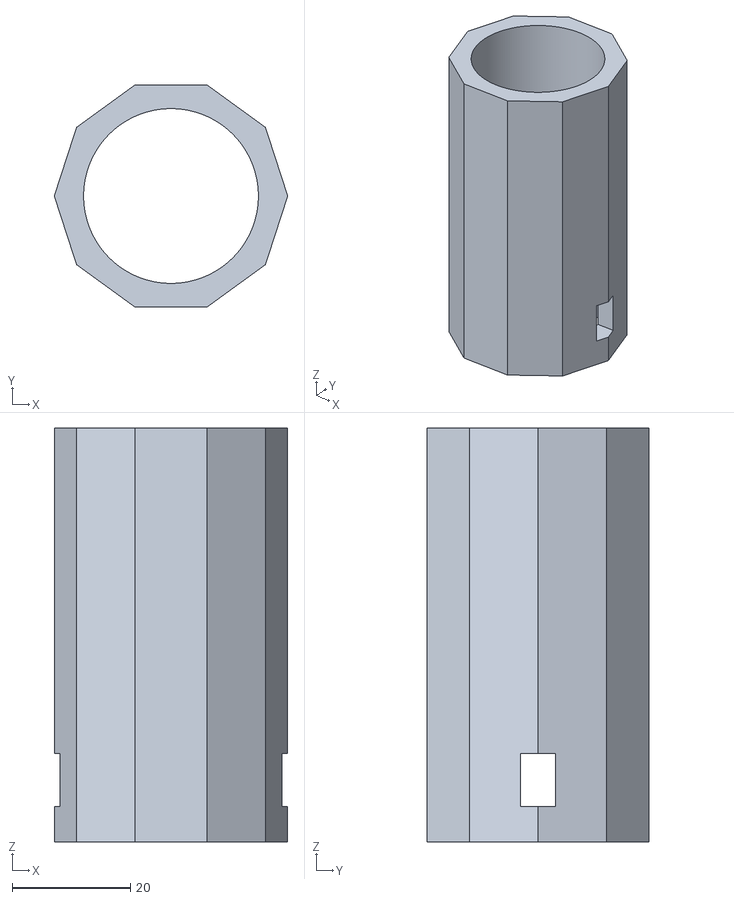
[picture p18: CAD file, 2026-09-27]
hardware/flame-bulb/core.stl
39.5 x 37.5 x 70.0

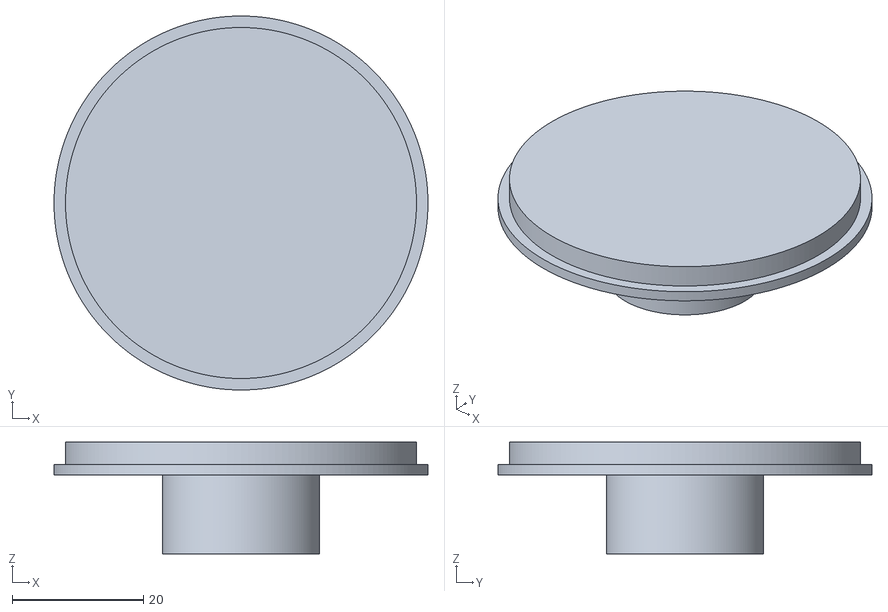
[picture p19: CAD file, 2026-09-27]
hardware/flame-bulb/cap-shell-variant.stl
57.0 x 57.0 x 17.0

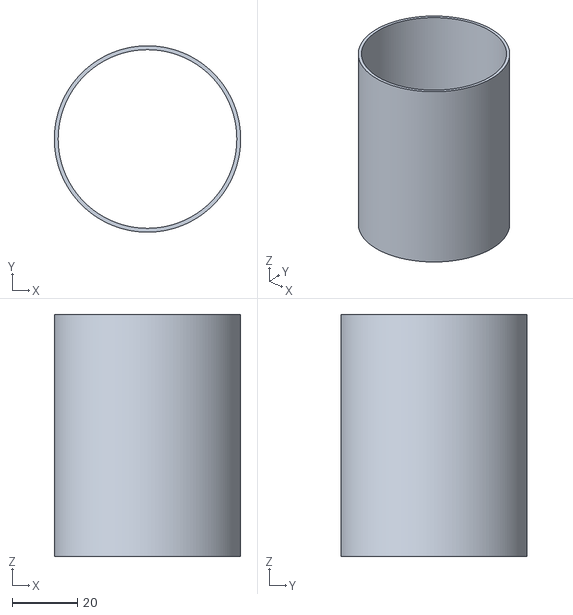
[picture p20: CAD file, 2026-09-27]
hardware/flame-bulb/diffuser.stl
57.0 x 57.0 x 74.0

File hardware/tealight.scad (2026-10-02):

// Smart tea light body — parametric, three printed parts.
//
//   part = "cup"      lower body: battery, perfboard, XIAO, button, USB-C slot   (opaque PETG)
//   part = "carrier"  spacer that sits on the perfboard and carries the LED ring (opaque PETG)
//   part = "cap"      diffuser dome, plugs into the cup                          (translucent PETG)
//   part = "all"      assembled preview (exploded = true to spread the parts)
//
// Render each part:  openscad -D 'part="cup"' -o cup.stl tealight.scad
//
// Stack (z, mm): floor 0–1 | cell 1–10 | perfboard 10–11.6 | XIAO 11.6–15.6
//                | carrier 11.6–15.6 | LED ring 15.6–19.1 | cap cavity to 22 | top 23
//
// Rev 2 (2026-10-02): od 38→40 and wall 1.0→1.6 — an 802030 cell's diagonal is
// 36.06 mm and the old Ø36 bore did not clear it; 1.0 mm PETG walls were too
// flexible for the cap's friction fit. cell_h 8.5→9.0 (pouch swell), paid for
// by carrier_h 4.5→4.0 (the XIAO is 4.0 tall). Ledge tabs → a ledge ring.
// Mechanical button removed: the XIAO nRF54L15's on-board LSM6DSO does
// tap-to-toggle / double-tap-for-ship-mode with no hole and no switch.

part = "all";
exploded = false;

// ---- dimensions -------------------------------------------------------
od        = 40;    // Ø40: fits an 802030 cell's 36.06 mm diagonal with 1.6 mm walls; holders are 38–40
wall      = 1.6;                  // 4 perimeters at 0.4 mm
id        = od - 2*wall;          // 36.8
floor_t   = 1.0;
cell_h    = 9.0;                  // 802030 cell (8.0 nominal) + ~10 % lifetime swell
perf_t    = 1.6;
perf_d    = 34;
ledge_z   = floor_t + cell_h;     // 10.0: perfboard rests here
ledge_w   = 2.0;  ledge_t = 1.5;   // perfboard ledge ring (rev 2: was three 1.5 mm tabs)
cup_h     = 15.5;                 // cup rim
cap_h     = 7.5;                  // cap above the rim → total 23
skirt_h   = 2.0;                  // cap plug depth into the cup
clr       = 0.2;                  // fit clearance

ring_od   = 32;   ring_id = 18;   ring_t = 1.6;  led_h = 1.9;
carrier_od = 34;  carrier_id = 29;  carrier_h = 4.0;   // = XIAO height
xiao_cut_x = 11;                  // carrier is cut away for x > this (XIAO + USB-C)

usb_w = 10;  usb_z0 = ledge_z + perf_t - 0.3;   // USB-C slot, from just under the XIAO's board edge up to the rim

$fn = 120;

// ---- cup -------------------------------------------------------------
module cup() {
  difference() {
    cylinder(d = od, h = cup_h);
    // cavity
    translate([0, 0, floor_t]) cylinder(d = id, h = cup_h);
    // USB-C notch, +x side, open at the rim
    translate([id/2 - 1, -usb_w/2, usb_z0]) cube([wall + 2, usb_w, cup_h]);
  }
  // perfboard ledge ring, interrupted on the USB (+x) side so the XIAO's
  // connector and cable clear it
  translate([0, 0, ledge_z - ledge_t]) difference() {
    cylinder(d = id + 0.02, h = ledge_t);
    translate([0, 0, -1]) cylinder(d = id - 2*ledge_w, h = ledge_t + 2);
    rotate([0, 0, -40]) rotate_extrude(angle = 80) square([id, ledge_t + 2]);
  }
}

// ---- carrier (spacer between perfboard and LED ring) --------------------
module carrier() {
  difference() {
    cylinder(d = carrier_od, h = carrier_h);
    translate([0, 0, -1]) cylinder(d = carrier_id, h = carrier_h + 2);
    translate([xiao_cut_x, -od/2, -1]) cube([od, od, carrier_h + 2]);
  }
}

// ---- cap (diffuser) ------------------------------------------------------
module cap() {
  // outer shell, rounded top edge
  difference() {
    hull() {
      cylinder(d = od, h = cap_h - 2);
      translate([0, 0, cap_h - 2]) rotate_extrude() translate([od/2 - 2, 0]) circle(r = 2);
    }
    translate([0, 0, -1]) cylinder(d = id, h = cap_h - wall + 1);
  }
  // plug skirt, notched for the USB-C
  translate([0, 0, -skirt_h]) difference() {
    cylinder(d = id - 2*clr, h = skirt_h + 0.01);
    translate([0, 0, -1]) cylinder(d = id - 2*clr - 2*wall, h = skirt_h + 2);
    translate([id/2 - 3, -(usb_w + 2)/2, -1]) cube([5, usb_w + 2, skirt_h + 2]);
  }
}

// ---- reference geometry for the preview (not printed) -------------------
module electronics() {
  color("orange", 0.5) translate([-10, -15, floor_t]) cube([20, 30, 8]);                 // 802030 cell (corners at r=18.03 < id/2=18.4)
  color("green", 0.6)  translate([0, 0, ledge_z]) cylinder(d = perf_d, h = perf_t);      // perfboard
  color("steelblue", 0.7) translate([-5.8, -8.75, ledge_z + perf_t]) cube([21, 17.5, 4]); // XIAO nRF54L15 (same outline as the C6)
  color("white", 0.8) translate([0, 0, ledge_z + perf_t + carrier_h]) difference() {     // LED ring
    cylinder(d = ring_od, h = ring_t); translate([0,0,-1]) cylinder(d = ring_id, h = ring_t + 2); }
}

// ---- assembly ------------------------------------------------------------
gap = exploded ? 12 : 0;
if (part == "cup") cup();
else if (part == "carrier") carrier();
else if (part == "cap") cap();
else {
  color("dimgray") cup();
  electronics();
  color("dimgray") translate([0, 0, ledge_z + perf_t + gap]) carrier();
  color("lightyellow", 0.5) translate([0, 0, cup_h + 2*gap]) cap();
}

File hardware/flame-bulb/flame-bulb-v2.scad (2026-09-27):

// Flame bulb v2 — PSU INSIDE the LED mast, strips run the full height.
// Three printed parts:
//   part = "cap"    E26 plug cup + Ø57 lip + spigot into the mast    PC-FR (mains)
//   part = "mast"   10-facet tube: PSU stands in the bore, XIAO above it,
//                   SK6812 strips on the facets from bottom to top      PC-FR (mains inside)
//   part = "shade"  Ø57 tube with a closed top, slides down over the
//                   mast onto the cap lip                               TRANSLUCENT PETG
//   part = "all"    preview (exploded = true)
//
// UNTESTED. HLK-10M05 = 47 x 28 x 22; 36 mm diagonal upright -> Ø37 bore.

part = "all"; exploded = false;

od = 57; diff_wall = 1.2; clr = 0.3;
psu_l = 47; psu_w = 28; psu_t = 22;
bore   = 37;                          // clears the PSU's 28x22 end with margin
n_facets = 10; strip_w = 12; facet_w = strip_w + 0.2;
core_r_min = facet_w / (2 * sin(180 / n_facets));      // radius needed for the strips
core_r     = max(core_r_min, bore/2 + 1.8);            // or bore + 1.8 mm wall
core_f2f   = 2 * core_r * cos(180 / n_facets);
n_px   = 15;                          // pixels per column at 6.94 mm -> 150 px total (T19 height)
mast_h = n_px * 6.94 + 2;             // 85.3
cap_lip = 3; spigot_h = 6;            // short lip: retention only, the mast's top fins centre the shade
// Shade runs right down over the cap lip, ending flush at the E26 plug (the
// lip is sized to the shade bore; glue or friction retains it).
shade_over_lip = true;
lip_d = shade_over_lip ? od - 2*diff_wall - 2*clr : od;
e26_body_d = 26.5; e26_cup_h = 12; e26_wall = 2.5;
shade_h = mast_h + 6 + (shade_over_lip ? cap_lip : 0); shade_cap = 1.6;
$fn = 160;

module cap() {
  difference() {
    union() {
      cylinder(d = lip_d, h = cap_lip);                                  // lip (inside the shade)
      translate([0, 0, cap_lip]) cylinder(d = bore - 2*clr, h = spigot_h); // into the mast bore
      translate([0, 0, -e26_cup_h]) cylinder(d = e26_body_d + 2*e26_wall, h = e26_cup_h + 0.01);
    }
    translate([0, 0, -e26_cup_h - 1]) cylinder(d = e26_body_d, h = e26_cup_h + 1 - 2); // plug cup, 2 mm floor
    translate([0, 0, -e26_cup_h - 1]) cylinder(d = 9, h = e26_cup_h + cap_lip + spigot_h + 2); // mains leads
  }
}

fin_h = 8; fin_t = 1.2;               // centring fins at the mast top, out to the shade bore
module mast() {
  difference() {
    union() {
      cylinder(r = core_r, h = mast_h, $fn = n_facets);
      // three thin fins on facet corners reach the shade bore and centre it
      for (a = [0, 120, 240]) rotate([0, 0, a + 18])
        translate([0, -fin_t/2, mast_h - fin_h]) cube([od/2 - diff_wall - clr, fin_t, fin_h]);
    }
    translate([0, 0, -1]) cylinder(d = bore, h = mast_h + 2);            // PSU + XIAO live here
    // strip power/data exit at the bottom of one facet
    translate([0, -3, spigot_h + 1]) cube([core_r + 1, 6, 8]);
    // notch at the top for the GND ring's lead back down the bore
    translate([-core_r - 1, -2, mast_h - 8]) cube([core_r + 1 - bore/2 + 1, 4, 9]);
    // vent slots near the top of two opposite facets (PSU makes ~3 W of heat)
    for (a = [90, 270]) rotate([0, 0, a]) translate([core_r - 4, -1.5, mast_h - 14]) cube([6, 3, 10]);
  }
}

module shade() {
  difference() {
    union() { cylinder(d = od, h = shade_h - 2); translate([0, 0, shade_h - 2]) cylinder(d1 = od, d2 = od - 4, h = 2); }
    translate([0, 0, -1]) cylinder(d = od - 2*diff_wall, h = shade_h - shade_cap + 1);
  }
}

g = exploded ? 22 : 0;
if (part == "cap") cap();
else if (part == "mast") mast();
else if (part == "shade") shade();
else {
  color("dimgray") cap();
  color("dimgray") translate([0, 0, cap_lip + g]) mast();
  color("steelblue", 0.7) translate([-psu_w/2, -psu_t/2, cap_lip + spigot_h + 1 + g]) cube([psu_w, psu_t, psu_l]);   // PSU
  color("royalblue", 0.8) translate([-10.5, -2, cap_lip + spigot_h + psu_l + 4 + g]) cube([21, 4, 17.8]);          // XIAO on edge
  color("lightyellow", 0.30) translate([0, 0, (shade_over_lip ? 0 : cap_lip) + 2*g]) shade();
}

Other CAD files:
hardware/flame-bulb/top.stl
hardware/flame-bulb/flame-bulb.3mf
hardware/flame-bulb/flame-bulb.scad

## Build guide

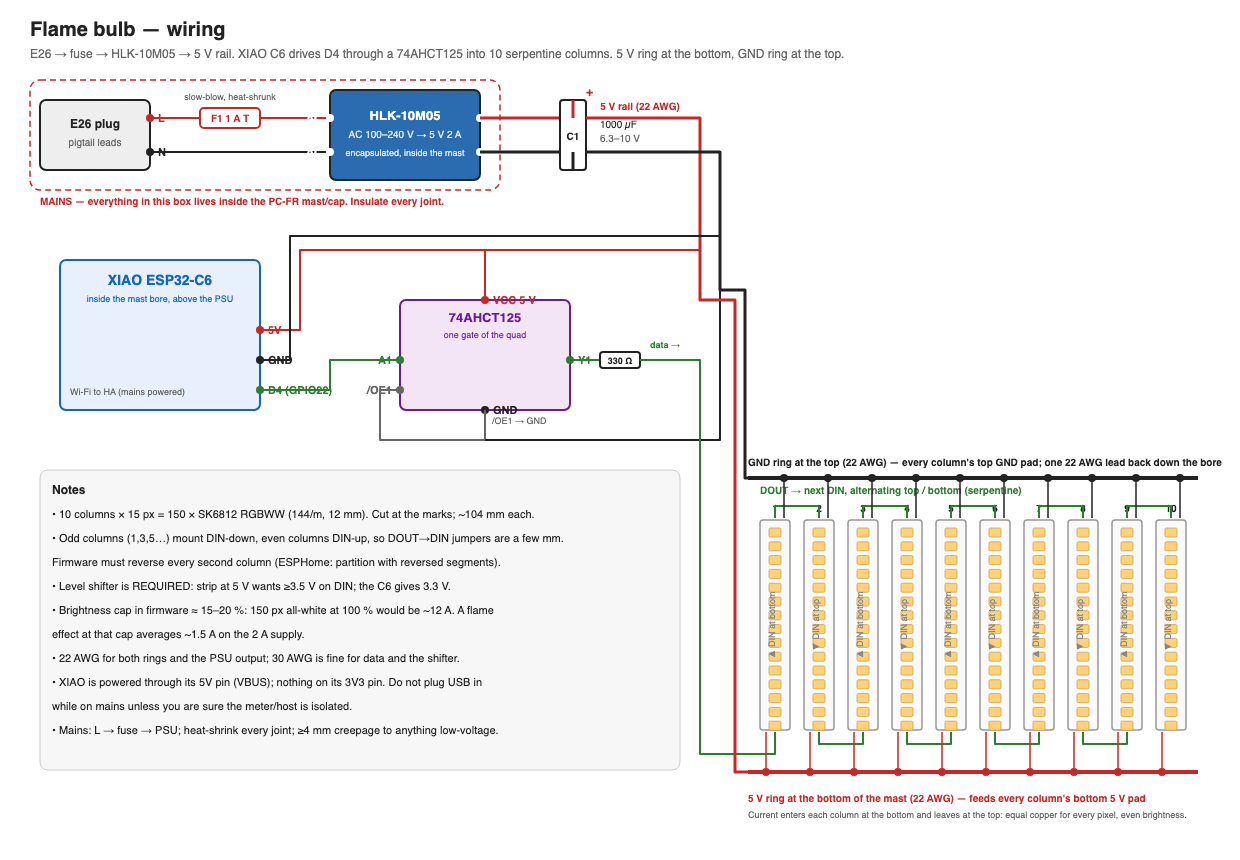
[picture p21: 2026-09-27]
docs/flame-bulb-wiring.png

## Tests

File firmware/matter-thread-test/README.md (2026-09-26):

# Matter over Thread test on the XIAO ESP32-C6

Goal: prove the C6 can join your Home Assistant as a Matter-over-Thread
light through the existing OpenThread Border Router, using Espressif's stock
`light` example with two small XIAO-specific tweaks. No custom app yet.

Budget: the esp-matter checkout is ~10 GB and the first build takes
20–40 min on a Mac. Everything below runs on the Mac, not in the cloud.

## 1. Install ESP-IDF + esp-matter (once)

```bash
mkdir -p ~/esp && cd ~/esp
git clone --recursive https://github.com/espressif/esp-idf.git
cd esp-idf && git checkout v6.0.2 && git submodule update --init --recursive
./install.sh esp32c6
cd ..

source esp-idf/export.sh
git clone --depth 1 https://github.com/espressif/esp-matter.git
cd esp-matter
git submodule update --init --depth 1
cd connectedhomeip/connectedhomeip
./scripts/checkout_submodules.py --platform esp32 darwin --shallow
cd ../..
./install.sh
cd ..
```

Every new terminal:

```bash
source ~/esp/esp-idf/export.sh
source ~/esp/esp-matter/export.sh
export IDF_CCACHE_ENABLE=1
```

## 2. XIAO tweaks to the light example

```bash
cd ~/esp/esp-matter/examples/light
cp ~/dev/smart-tealight/firmware/matter-thread-test/sdkconfig.xiao_c6 .
```

Then in `main/app_main.cpp`, add the include and the RF-switch block from
[`xiao_rf_switch.inc`](xiao_rf_switch.inc): the include at the top, the block
as the **first lines of `app_main()`** (before `nvs_flash_init()`). Without it
the radio is connected to no antenna (same trap as ESPHome).

## 3. Build, flash, watch

```bash
idf.py -D SDKCONFIG_DEFAULTS="sdkconfig.defaults;sdkconfig.defaults.c6_thread;sdkconfig.xiao_c6" set-target esp32c6 build
idf.py -p /dev/cu.usbmodem101 flash monitor
```

In the monitor you should see OpenThread start and BLE advertising for
commissioning. The example ships with the Matter **test** credentials:

| | |
|---|---|
| Manual pairing code | `34970112332` |
| QR payload | `MT:Y.K9042C00KA0648G00` |
| Passcode / discriminator | `20202021` / `3840` |

(`matter onboardingcodes ble` in the monitor's console prints them too.)

## 4. Commission from Home Assistant

HA → Settings → Devices & services → **Matter** → Add device → *Add Matter
device* → enter the manual code (or scan the QR from the phone app). HA's
Matter server commissions over BLE, hands the device your Thread network
credentials from the OTBR, and it joins as a Thread end device. You get an
"Extended Color Light" with on/off, brightness and colour.

Test-credential caveat: HA accepts them (it warns about the test DAC). Real
products need their own attestation cert; for our own devices we keep using
test certs and click through.

## 5. What to measure

* **Does it commission and stay reachable?** Toggle it from HA a dozen
  times over ten minutes. Thread signal → HA Thread panel shows the device.
* **Sleep current.** The stock example is *not* a sleepy end device: expect
  ~20–40 mA idle. That's fine for this test; ICD/SED config is step 6.
* **RF switch:** if BLE advertising never shows up on the phone or
  commissioning times out, re-check the `xiao_rf_switch.inc` block.

## 6. Next (after this passes)

* Turn it into a sleepy end device: `CONFIG_ENABLE_ICD_SERVER=y`,
  `CONFIG_PM_ENABLE=y`, `CONFIG_FREERTOS_USE_TICKLESS_IDLE=y`, ICD slow-poll
  interval ~1 s; measure with a USB power meter — the target is ≤200 µA idle.
* Then the real app in `firmware/tealight/`: WS2812 ring on D4 (GPIO22)
  via the BSP RMT driver, warm LED PWM on D2, ring rail on D3, Mode Select
  endpoint for effects, battery via Power Source cluster.

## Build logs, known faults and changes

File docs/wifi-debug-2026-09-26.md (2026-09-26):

# Wi-Fi bring-up problem — RESOLVED 2026-09-26

**Cause: a case typo in `secrets.yaml`** (`Iot` vs `IoT`). ESPHome's
`No networks found` means *no network matching the configured SSID*, not an
empty scan, which sent the debugging down the antenna-switch path.

**Lesson for the notes:** on "No networks found", check the SSID spelling
first; add `fast_connect: false` + DEBUG and look for the actual scan
results before suspecting hardware.

The XIAO C6 antenna-switch handling (`enable_on_boot: false`, GPIO3/GPIO14
set from `on_boot`, then `wifi.enable`) stays in the config: it's how the
board's ceramic/U.FL antenna gets selected and it's what Seeed's own
Arduino variant does.

---

Original investigation, kept for reference:

**Symptom:** XIAO ESP32-C6 running ESPHome scans and finds **zero** networks
(`[W][wifi:1506]: No networks found`), then loops through
RETRY_HIDDEN → "Probe Request Unsuccessful" → restart adapter.

**Ruled out so far (all give the identical result):**
- Two different XIAO C6 boards (MACs …1A:EB:00 and …13:79:FC)
- ESPHome 2026.9.0 (brew) and 2026.5.0 (venv) — same YAML
- Full `tealight-c6.yaml` with GPIO3/GPIO14 driven at on_boot priority 600
  (both antenna settings) — note ESPHome starts Wi-Fi ~7 ms into setup(),
  before on_boot 600, so those writes were probably too late
- `minimal-c6.yaml` without any antenna handling
- `minimal-c6.yaml` with `wifi.enable_on_boot: false` and the pins set from
  on_boot before `wifi.enable` (ceramic antenna selected)
- Arduino framework: not supported by ESPHome on the C6, could not test

**Not yet checked:**
- The `enable_on_boot: false` minimal with `antenna_select` turned **on**
  (U.FL) — bench board has an external antenna attached
- Whether the config dump actually shows `[C][gpio.output]` for GPIO3/14
  (i.e. the antenna block really compiled in)
- Multimeter on the GPIO3 / GPIO14 pads after boot (expect 0 V / 0 V or 3.3 V)
- Environment sanity: a phone next to the board sees 2.4 GHz networks?
- A non-ESPHome firmware (plain ESP-IDF wifi scan example) as a reference
- Seeed forum / ESPHome issues for "No networks found" on this board revision

**Board facts:** GPIO3 = WIFI_ENABLE (low powers the RF switch),
GPIO14 = WIFI_ANT_CONFIG (low = ceramic, high = U.FL). Neither is on the
header. Seeed's Arduino variant drives both low in initVariant().

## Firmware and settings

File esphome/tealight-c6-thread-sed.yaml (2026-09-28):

# Smart tea light — ESPHome over THREAD, SLEEPY END DEVICE (XIAO ESP32-C6)
#
# Attach workaround (2026-09-26): ESPHome applies the Thread link mode in
# apply_linkmode_() *before* the dataset is activated and the stack is
# started, and the restored NetworkInfo then clobbers it — an MTD ends up
# advertising (rx_on=0, dev=0, nd=0), i.e. sleepy, from its very first Child
# ID Request, and the attach never completes (Child ID Request -> no
# response, DataReq -> NoAck, forever). Re-asserting rx_on_when_idle=1 once
# the stack is running attaches as a child in ~1 s. So: come up as a Minimal
# End Device, attach, then go sleepy from the go_sleepy script.
#
# Phase 2 of tealight-c6-thread.yaml: the radio polls its parent once a
# second (MTD + poll_period) and the CPU light-sleeps between events via the
# esp32_pm component from esphome/esphome#12325 (unmerged; pulled from the
# PR branch as an external component — measured 105 µA average on a C6).
#
# Things to measure on the USB power meter, in this order:
#   1. idle, both lights off            target ≤ 0.2 mA (vs ~17 mA without PM)
#   2. candle mode (LEDC PWM running)   does the PWM survive light sleep?
#   3. ring on                          rail on, CPU busy → no sleep, expected
#   4. HA → light on latency            ≤ poll_period + a bit
# OTA: turn on the "Radio always on" switch first (esphome.ota can't push to
# a sleeping device), then turn it off again afterwards.
#
# Thread credentials come from HA: Settings → Thread → ⋮ → the preferred
# network's dataset (or the otbr/info websocket call). Put them in
# secrets.yaml as thread_channel / thread_network_name / thread_network_key /
# thread_pan_id / thread_ext_pan_id / thread_pskc / thread_mesh_local_prefix.

substitutions:
  name: tealight-sed
  friendly_name: Tealight SED
  ring_leds: "8"
  # Brightness cap for the ring (battery + charger protection). 40 % of 8
  # full-white LEDs is still ~160 mA.
  ring_cap: 40%
  # "true" = U.FL external antenna (bench board), "false" = onboard ceramic
  external_antenna: "false"
  # With name_add_mac_suffix the dashboard would look for ${name}.local, which
  # doesn't exist. Give it the real hostname (or the fd99:… IPv6 address).
  use_address: tealight-sed-1379fc.local

esphome:
  name: ${name}
  friendly_name: ${friendly_name}
  name_add_mac_suffix: true
  # XIAO C6 antenna switch, set before any radio initialises (priority
  # 1000 runs before all component setup). See xiao_c6_rf_switch.h.
  includes:
    - xiao_c6_rf_switch.h
  on_boot:
    - priority: 1000
      then:
        - lambda: xiao_c6_rf_switch(${external_antenna});
    # Auto-sleepy is back ON. It was disabled because the attach watchdog had
    # no hysteresis and cancelled sleepy at the first transient detach, which
    # left the radio awake while the switch still read "on". The watchdog now
    # gives sleepy two minutes and falls back honestly if it cannot hold.

esp32:
  board: seeed_xiao_esp32c6
  variant: esp32c6
  framework:
    type: esp-idf
    sdkconfig_options:
      # REQUIRED for sleepy operation. Espressif's ot_sleepy_device reference
      # sets this, and esp32_pm only disables ND6 when poll_period is set at
      # COMPILE time — we set it at runtime, so that guard never fires.
      # With ND6 on, IPv6 Neighbour Discovery keeps probing; once the radio
      # stops listening the probes fail, the neighbour goes unreachable and
      # the interface drops ("Network down; disconnect") within seconds.
      CONFIG_LWIP_ND6: "n"
      # ESP-IDF blocks automatic light sleep while the USB Serial/JTAG
      # peripheral is connected to a host, so any USB-side power measurement
      # reads the never-sleeping number. Allow sleep regardless.
      CONFIG_USJ_NO_AUTO_LS_ON_CONNECTION: "n"
      # Pure IPv6 to HA; the DNS64 client is never used.
      CONFIG_OPENTHREAD_DNS64_CLIENT: "n"
      # Was recalibrating the internal RC oscillator on *every* sleep entry.
      CONFIG_PM_LIGHTSLEEP_RTC_OSC_CAL_INTERVAL: "8"
      # TEST 2026-09-28: these three are what esp32_pm's enable_light_sleep
      # pulls in. They power down the radio/baseband across light sleep and
      # rely on the RTC slow clock to bring it back at the right instant.
      # This board has no 32.768 kHz crystal (internal RC, ~5% drift), which
      # is the likeliest reason a SED can never complete an MLE attach here.
      # ESPHome's sdkconfig entries are sticky, so they must be set "n"
      # explicitly — clearing enable_light_sleep alone does not remove them.
      CONFIG_IEEE802154_SLEEP_ENABLE: "y"
      CONFIG_ESP_PHY_MAC_BB_PD: "y"
      CONFIG_FREERTOS_USE_TICKLESS_IDLE: "y"

globals:
  - id: detached_since
    type: uint32_t
    restore_value: false
    initial_value: "0"
  - id: sleepy_gave_up
    type: bool
    restore_value: false
    initial_value: "false"
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

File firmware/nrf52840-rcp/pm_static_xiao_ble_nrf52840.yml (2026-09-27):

# Adafruit UF2 bootloader layout on the XIAO nRF52840 (app starts at 0x27000).
softdevice_reserved:
  address: 0
  size: 159744
app:
  address: 159744
  size: 806912
settings_storage:
  address: 966656
  size: 32768
uf2_partition:
  address: 999424
  size: 49152

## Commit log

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2026-09-26 Track B: ESP-Matter on the ESP32-C6 instead of a separate nRF board
    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
2026-09-26 ESPHome: don't enter ship mode when no battery is connected
    With D0 floating the ADC reads ~0 V, which tripped the low-battery
    deep-sleep rule about a minute after boot on a USB-only bench board.
    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
2026-09-26 ESPHome: enable the XIAO C6 RF switch at boot
    Without GPIO3 driven low the radio is disconnected from both antennas
    and Wi-Fi scans return no networks.
    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
2026-09-26 ESPHome: set the C6 antenna switch then restart Wi-Fi after boot
    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
2026-09-26 ESPHome: hold Wi-Fi off at boot until the C6 antenna switch is set
    ESPHome starts Wi-Fi first thing in setup(), before on_boot runs, so
    the PHY was initialising with the RF switch unpowered.
    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
2026-09-26 Remove Arduino bench config: ESPHome does not support Arduino on the C6
    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
2026-09-26 Wi-Fi debug note: resolved (SSID case typo in secrets)
    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
2026-09-26 ESPHome over Thread config for the XIAO C6 (phase 1: FTD)
    Plus a header that sets the XIAO C6 antenna switch from on_boot at
    priority 1000, before any radio initialises.
    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
2026-09-26 ESPHome over Thread confirmed working; Matter track demoted to fallback
    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
2026-09-26 ESPHome over Thread phase 2: sleepy end device + esp32_pm light sleep
    MTD with a 1 s poll period, the esp32_pm component from
    esphome/esphome#12325 as an external component, and a 'Radio always on'
    switch to allow OTA.
    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
2026-09-26 Thread configs: explicit use_address so the dashboard finds the device
    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
2026-09-26 SED config: correct use_address hostname
    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
    [tealight-c6-thread-sed.yaml]
2026-09-26 3D-printable body: parametric OpenSCAD, STLs, preview; flame-bulb idea note
    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
    [cap.stl, carrier.stl, cup.stl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]
2026-09-26 Flame bulb idea: SK6812 RGBWW 144/m at 5 V instead of WS2805
    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
2026-09-26 SED config: attach with the radio on, go sleepy at runtime once HA is connected
    A device configured sleepy from boot never completed the Thread attach.
    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
2026-09-26 Bisect the sleepy-end-device failure: MTD and esp32_pm each block the Thread attach
    Claude-Session: https://claude.ai/code/session_01HB7AjFiE1eQpQDTaRniowe
    [bisect-c-mtd-runtime.yaml]
2026-09-26 Correct the bisect: esp32_pm is fine, MTD is the only blocker; U.FL path is dead
    The earlier PM conclusion was drawn from runs on the external antenna,
    which does not work on this board.
    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
2026-09-26 Root-cause the MTD attach failure and ship a working Thread MED config
    ESPHome applies the Thread link mode before the stack starts, so an MTD
    comes up sleepy and never completes the attach. Add a detach watchdog that
    re-asserts rx-on-when-idle, making MTD usable; sleepy polling still drops
    the link and is now an experimental, self-recovering switch.
    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
    [bisect-d-mtd-role.yaml, bisect-e-mtd-med.yaml, bisect-f-sed-instrumented.yaml]
2026-09-27 Sleepy failure reproduces on a new router and fresh Thread network
    Rules out the SLZB RCP, stale child table and interference; the fault is
    on the C6/ESPHome side.
    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
2026-09-27 Add print-ready 3MF and the sleepy-without-PM experiment config
    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
    [tealight.3mf]
2026-09-27 Fix the sleepy attach with CONFIG_LWIP_ND6=n; data delivery still fails
    ND6 probes were tearing down the interface once the radio stopped
    listening. With it off the device stays attached while sleepy, but the
    parent still does not deliver queued traffic, so the API dies ~70s in.
    Auto-sleepy disabled; switch kept for manual testing.
    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
    [exp1-sleepy-nopm.yaml, exp2-linkquality.yaml, exp3-nd6-off.yaml]
2026-09-27 Flame bulb: parametric body, STLs and 3MF; reusable 3MF packer
    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
    [base.stl, cap.stl, core.stl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]
2026-09-27 Flame bulb: one-piece shade (tube + closed top), printed closed end down
    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
    [flame-bulb.3mf, flame-bulb.scad, shade.stl]
2026-09-27 Flame bulb: 10 columns of 12 mm strip (100 px), facet count parametrised
    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
    [base.stl, core.stl, flame-bulb.3mf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]
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2026-09-27 Flame bulb: cap takes an E26 pigtail plug in a cup; BOM and diagram updated
    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
    [cap.stl, flame-bulb.3mf, flame-bulb.scad]
2026-09-27 Flame bulb cap: plug-cup or shell-boss selectable; BOM lists the BLLNDX plug
    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
    [cap-shell-variant.stl, flame-bulb.3mf, flame-bulb.scad]
2026-09-27 nRF54L15: Matter-over-Thread sleepy light bulb app for the XIAO (builds, untested)
    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
2026-09-27 Flame bulb: PSU on its side (base 56 -> 41 mm), orientation parametrised; blind core socket
    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
    [base.stl, flame-bulb.3mf, flame-bulb.scad]
2026-09-27 Flame bulb v2: PSU inside the LED mast, strips full height, ~111 mm, 120 px
    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
    [base.stl, cap.stl, flame-bulb-v2.3mf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]
2026-09-27 Flame bulb v2: T19 height, 15 px per column (150 px)
    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
    [flame-bulb-v2.3mf, flame-bulb-v2.scad, v2-mast.stl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]
2026-09-27 Flame bulb v2: shade runs down over an 8 mm cap lip to the E26 plug
    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
    [flame-bulb-v2.3mf, flame-bulb-v2.scad, v2-cap.stl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]
2026-09-27 Flame bulb: wiring diagram (5 V ring bottom, GND ring top, serpentine data); v2 short lip + centring fins
    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
    [flame-bulb-v2.3mf, flame-bulb-v2.scad, v2-cap.stl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]
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2026-09-27 nRF52840 Matter: drop factory data (DFU never flashes it); board now advertises
    The Adafruit bootloader programs only the app image, so the generated
    factory_data partition never reached the chip and the app sat silent at
    boot. Use the CHIP test identity instead. Confirmed on hardware: console
    on CDC ACM, Matter commissionable advert (0xFFF6, VID 0xFFF1/PID 0x8005,
    discriminator 3840). Also: BOM level shifter is now the SN74AHCT125N with
    a note on why auto-direction shifters (TXS0108E) are the wrong part.
    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
2026-09-27 Stop tracking build dirs (build-noicd, otcli build) — ignore build*/
    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
2026-09-27 Add SMLIGHT MR4U sleepy-Thread bug report
    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
2026-09-27 Add nRF52840 (XIAO) OpenThread RCP build — spinel over USB CDC
    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
2026-09-27 OTBR compose: SLZB-06 CC2652P RCP defaults, by-id device, backbone env
    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
2026-09-27 Finding 9: sleepy failure reproduces on SLZB-06 USB RCP — border router exonerated; mark SMLIGHT report do-not-file
    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
2026-09-28 Keep the no-MPSL overlay referenced by Finding 9; ignore stray build logs
    overlay-nompsl.conf is cited in docs/thread-sed-bisect-2026-09-26.md as the
    experiment that fails to link, so it belongs in the tree. build*/ does not
    match build-nompsl.log, hence *.log.
    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
2026-09-28 Finding 11: C6 cannot attach as a sleepy end device; withdraw Finding 10
    The USB power meter showed 60 mA with Sleepy mode both on and off. Root
    cause of the false positive: the attach watchdog had no hysteresis and
    cancelled sleepy at the first transient detach, while the optimistic
    switch kept showing it enabled.
    Watchdog now has a grace period and reports honestly. With it out of the
    way, a sleepy C6 never re-attaches (role=1 for the full 120 s) in all
    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
2026-09-28 nRF54L15 Matter: boots as a sleepy ICD (was a crashing router)
    First hardware run of the nrf54-matter port on a Seeed XIAO nRF54L15.
    Four defects, all of which had to be fixed before a first commission:
    1. CONFIG_OPENTHREAD_FTD=y -> the board came up as a Thread ROUTER
    ("Setting OpenThread device type to ROUTER") with the radio always on,
    which would have silently destroyed battery life while looking fine.
    Now MTD + NORDIC_LIBRARY_MTD, same fix as nrf52840-matter.
    2. The XIAO defines a single led0, but Nordic's dk_buttons_and_leds builds
    its table from the children of /leds and Matter's AppTask drives
    DK_LED1..4 -> "LED index out of the range" -> USAGE FAULT at boot.
    Added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
2026-09-28 nRF54L15 Matter: commissioned into HA over Thread as a sleepy ICD
    Final fixes on top of b8b6abb:
    - CHIP_CRYPTO_PSA_MIGRATE_DAC_PRIV_KEY=n (the *choice member*
    CHIP_CRYPTO_PSA_DAC_PRIV_KEY_KMU=n was a silent no-op)
    - BLE TX power 0 -> +8 dBm to match the Thread radio (commissioning was
    dying with BLE supervision timeouts whenever the board sat near the
    border router instead of near the commissioner)
    - OpenThread shell on the Zephyr shell (+8 KB shell stack: `ot dataset
    set active <tlv>` overflowed the default) so the Thread dataset can be
    pre-provisioned over serial. That was the fix that mattered: the
    commissioner reconnects 2 s after connectNetwork, before a sleepy
    child has r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
2026-09-28 Finding 12: nRF54L15 commissioned into HA over Thread as a sleepy ICD; HA controls it
    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
2026-09-28 nRF54L15 Matter: Matter log level ERR for the current measurement build
    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
2026-09-29 docs: PPK2 + XIAO nRF54L15 + 802030 current-measurement wiring diagram
    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
2026-10-02 Tea light body rev 2: Ø40, 1.6 mm walls, ledge ring, no button hole; BOM: PSU sizing
    Body (tealight.scad, STLs, 3MF regenerated):
    - od 38 -> 40, wall 1.0 -> 1.6. An 802030 cell's diagonal is 36.06 mm and
    the old Ø36 bore did not clear it; 1.0 mm PETG was too flexible for the
    cap's friction fit. Bore is now Ø36.8 (corner radius 18.03 < 18.4).
    - cell_h 8.5 -> 9.0 for pouch swell, paid for by carrier_h 4.5 -> 4.0 (the
    XIAO is 4.0 tall). Stack still tops out at 23.0 mm.
    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
    [cap.stl, carrier.stl, cup.stl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]
